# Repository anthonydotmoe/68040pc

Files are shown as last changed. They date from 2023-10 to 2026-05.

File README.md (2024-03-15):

# 68040pc

Welcome to the `68040pc` (working name) project, an ambitious endeavor to build
a general-purpose computer platform powered by the Motorola 68040 (or, in this
case, the 68LC040) CPU. Inspired by creations like Ben Eater's breadboard 6502
computer and me finding a 68LC040 in a bin, this project seeks to bring the
charm of vintage computing into the modern era with a twist of power and
utility. Call me crazy, but I expect to be able to use this machine when it's
done.

## Status

The `testboard` design is almost complete. I'm going to sleep on the design
before ordering boards. The FPGA does address decoding and interrupt
management and will contain a sound core to output some cool beeps through
the I2S DAC module. I'm pleased with how the project is going so far!

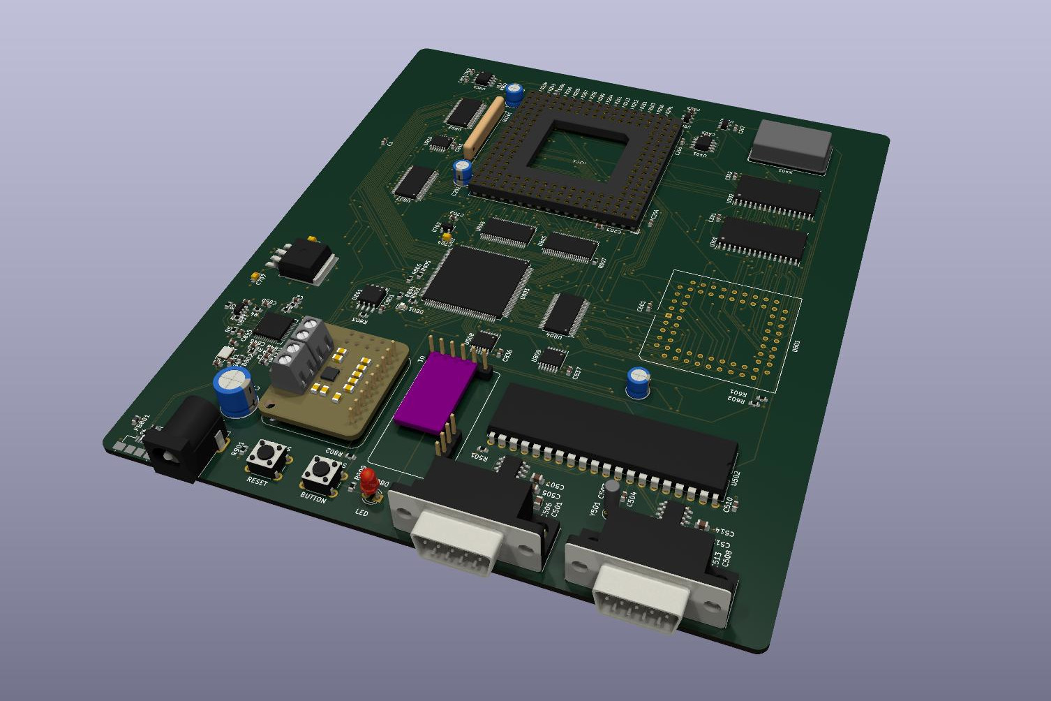
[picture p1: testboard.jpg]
testboard Render


## Objectives

The `68040pc` aims to be versatile and user-friendly, with the following
capabilities:
- **Input/Output**: Support for keyboard (text input) and mouse for GUI
  interactions.
- **Display**: Text display for command-line operations and a graphics display
  ready for GUI applications.
- **Storage**: Compatibility with standard bulk storage devices, including
  floppies and hard drives.
- **OS**: Capability to run a preemptive multitasking operating system.
- **Expansion**: A robust expansion system, ensuring the platform remains
  relevant and adaptable after its initial production.

## Performance Expectations

With the integration of the 68040 CPU and the potential to accommodate up to
512MB of RAM, I anticipate the `68040pc` will rival the performance metrics of
systems like the Amiga, especially in terms of computational power. Although the
base system might not match the Amiga's graphical prowess, there's potential for
future enhancements via expansion cards to bring it to that level.

## Learning and Documentation

This journey isn't just about creating a new machine—it's a significant learning
curve for me, and I want it to serve as an educational resource for others.
Every step of the way, the system will be meticulously documented. From design
decisions to implementation nuances, the goal is to demystify the process and
make the knowledge accessible to all.

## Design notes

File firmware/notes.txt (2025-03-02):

- Expose interrupt generator peripheral from FPGA

POST Routine:

- Do test of SRAM
	- SRAM works -> relocate VBR to SRAM
- Test interrupts
	- Interrupts work, serial port can use them
- Test serial port?

FPGA BASE:0x80000000
	* 0x00.l - Status
	* 0x04.b - Fire interrupt (number written, one cycle)

MMU Transparent translation

Addr		Device		DataC		InstC
0000_0000	ROM		01		01
2000_0000	DUART		11		11
3000_0000	SRAM		01		01
8000_0000	FPGA		11		11

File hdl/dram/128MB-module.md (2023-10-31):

SAMS-side pin 1 to pin 72 are 0-7
OKI-side  pin 72 to pin 1 are 8-15

| DRAM Chip # | CAS Line | RAS Line | Data Lines |
|---|---|---|---|
| 0 | CAS0 | RAS0 | D0-D3 |
| 2 | CAS0 | RAS0 | D4-D7 |
| 4 | CAS1 | RAS0 | D8-D11 |
| 6 | CAS1 | RAS0 | D12-D15 |
| 1 | CAS2 | RAS2 | D16-D19 |
| 3 | CAS2 | RAS2 | D20-D23 |
| 5 | CAS3 | RAS2 | D24-D27 |
| 7 | CAS3 | RAS2 | D28-D31 |
|---------------------------------------------------|
| 8 | CAS0 | RAS1 | D0-D3 |
| 10 | CAS0 | RAS1 | D4-D7 |
| 12 | CAS1 | RAS1 | D8-D11 |
| 14 | CAS1 | RAS1 | D12-D15 |
| 9 | CAS2 | RAS3 | D16-D19 |
| 11 | CAS2 | RAS3 | D20-D23 |
| 13 | CAS3 | RAS3 | D24-D27 |
| 15 | CAS3 | RAS3 | D28-D31 |

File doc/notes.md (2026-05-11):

# Ideas

* Use ATF1508 for the DRAM controller. This leaves more pins for a non-BGA FPGA
  to be useful.

## EDO DRAM Bursting Support

Use four matching 72-pin EDO SIMMs as one 512 MiB interleaved memory array, not
as four separate linear banks.

Each SIMM remains a 32-bit data source/sink. The CPU data bus is still only 32
bits wide. Only one SIMM drives the 68040 data bus per transfer beat.

Address mapping:

| Address Bits | Mapping |
|---|---|
| A1..A0 |  byte lane within longword |
| A3..A2 |  SIMM select / longword-in-16-byte cache line |
| A15..A4 |  12-bit DRAM column |
| A27..A16 |  12-bit DRAM row |
| A28 |  SIMM rank select |

A 16-byte cache line is distributed as:

| | |
|-----|---|
| +0  | SIMM 0 |
| +4  | SIMM 1 |
| +8  | SIMM 2 |
| +12 | SIMM 3 |

For burst/line fills, initialize the SIMM selector from A3..A2, then increment
modulo 4 each accepted /TA beat. This supports critical-word-first ordering:

| A[3:2] | Order |
|---|---|
| 00 | 0,1,2,3 |
| 01 | 1,2,3,0 |
| 10 | 2,3,0,1 |
| 11 | 3,0,1,2 |

All SIMMs share the same row/column address for a given line. With 12 column
bits and four 32-bit SIMMs interleaved, one open DRAM row group covers:

4096 columns × 16 bytes = 64 KiB

So naturally aligned 4 KiB MMU pages never straddle DRAM row groups.

# Problems

## XR68C681 DUART

I attempted to write a simple monitor ROM program for the 68040pc pretty early
on. I ran into problems when I reached the point of wanting user input.

### Original symptom

After not being able to debug my monitor CLI logic, I made a test program
intended to behave like a simple polling echo loop:

1. Poll SRA until `RxRDY` is set.
2. Read one byte from RBA
3. Poll SRA until `TxRDY` is set.
4. Write that byte to TBA.
5. Repeat.

The observed failure was that sending one character to the computer would
eventually result in an extra character being handled. At first this looked
like:

1. Host sends one character.
2. 68040 reads one character.
3. 68040 writes it to TBA.
4. Then the DUART appears to have another received character pending.

My early suspicion was that the DUART transmit write might somehow be making
`RxRDY` true, either through accidental loopback, or through my novice-level
Verilog controlling the bus behavior.

### Troubleshooting

* Terminal behavior

  I considered that maybe my tried and true `picocom` terminal emulator was the
  problem. I had ChatGPT generate a test program in Python that wrote out single
  bytes to the serial port, but no change was observed.

* Rewired DUART address lines:

  I moved the DUART `RS[4:1]` lines from `{ A[3:2], PA[1:0] }` to `A[5:2]`. The
  goal was to force accesses to always land on the same byte lane and remove
  byte-lane steering from the MC68150 as a varible. No change.

* Checked whether the 68150 was generating multiple accesses

  If the CPU was issuing a word or long word access to the DUART address space,
  the 68150 would generate multiple accesses to fill in the request. Probing the
  bus while testing did not give any evidence of duplicate DUART select cycles.

* Checked address setup relative to `/CS`

  With a logic analyzer, I determined that address setup time going into `/CS`
  was well within spec.

* Verified that the DUART was in the correct mode

  I changed the initialization routine to purposefully set up remote loopback
  mode, as the bits that do that were previously not being set. Remote loopback
  mode behaves completely differently, and behaves as expected. Characters are
  sent right through from the RX shift register to the TX shift register.

  I also tried automatic echo mode, and it behaved as expected.

* Considered accidental multidrop mode

  I remember seeing something about a different mode in the datasheet, so maybe
  I had the DUART in that mode. After looking into it further, the symptoms
  aren't consistent with having the DUART in the multidrop mode.

* Crystal wiring

  I had wired in the crystal to the DUART without much thought, and it turns out
  it is not what the datasheet has specified. I have capacitors inline with the
  crystal, but the reference design uses capacitors to ground on X1/CLK and X2.
  The DUART behaved well enough that I didn't think it would be possible for it
  to be an issue, but I was running out of things to try.

  I used a PLL in the FPGA to synthesize a 3.6805 MHz 3.3V clock signal. This is
  about 0.16% low relative to 3.6864 MHz, but it was within the error margin.
  No change.

* RxA/external serial line checks

  I scoped RxA and did not see any evidence of more than one character on the
  line for a given keypress in the terminal.

### Yet to confirm

* I haven't thoroughly checked the reset line on the DUART. I assume it's
  working because the first character the test program receives works without
  issue, but any subsequent characters end up repeating nonsense. However, I
  haven't completely tested it.

* The bus interface is not entirely without suspicion. I feel like I know enough
  about the 68040 bus to have wired everything and got the HDL correct, but I'm
  far from an expert on this and still have doubts.

### Remaining failure modes to consider

1. Reset/init does not fully clear the DUART receiver/FIFO/status state.
2. RBA read-clear behavior is not reliably recognized.
3. TBA write or nearby DUART bus access subtly corrupts internal state.
4. Register-select/read/write timing is marginal despite the cycle looking
   generally normal.
5. Data bus behavior causes stale/wrong RBA values to be read.
6. XR68C681 clone-specific quirk, board-level sensitivity, or undocumented
   behavior.

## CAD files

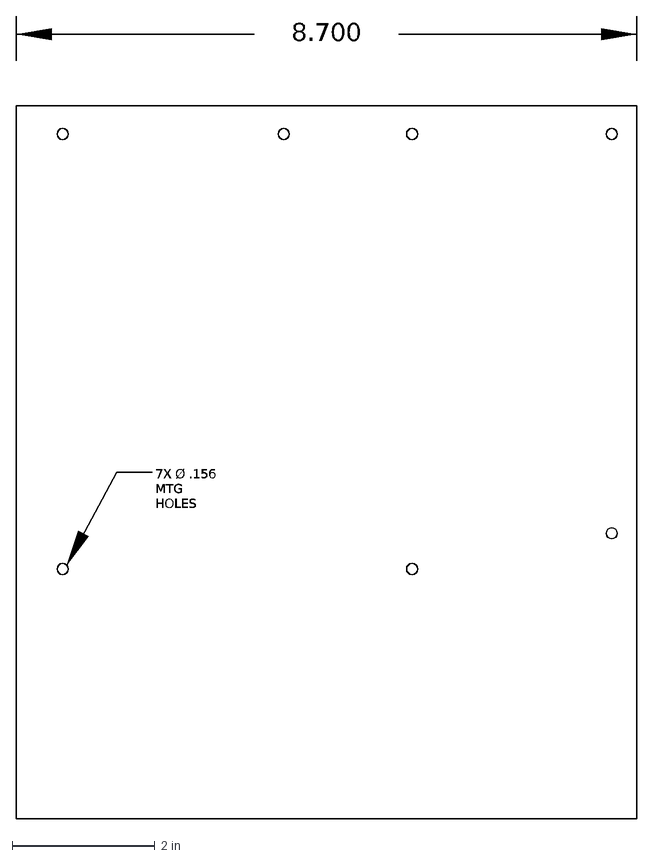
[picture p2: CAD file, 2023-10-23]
doc/board.dxf
7X Ø .156 MTG HOLES
8.700

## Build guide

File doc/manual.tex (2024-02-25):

\documentclass{article}

%\usepackage[letterpaper, margin=1in]{geometry}
\usepackage[letterpaper]{geometry}
\usepackage{bold-extra}
\usepackage{bytefield}
\usepackage{tabularx}
\usepackage{threeparttable}
\usepackage{xifthen}
\usepackage{xparse}
\usepackage{xspace}

\newcommand{\systemname}[0]{68040pc\xspace}

\makeatletter
\newcommand*{\textoverline}[1]{$\overline{\hbox{#1}}\m@th$}
\makeatother

\newcommand{\textss}[1]{$_{\hbox{#1}}$}

\NewDocumentCommand{\addr}{mm}{%
  \IfNoValueTF{#2}
  	{\texttt{\$#1}}
	{\mbox{\texttt{\$#1}-\texttt{\$#2}}}
}

\newcommand{\memsection}[4]{
	\bytefieldsetup{bitheight=#3\baselineskip}
	\bitbox[]{10}{
		\texttt{#1}
		\\ \vspace{#3\baselineskip} \vspace{-2\baselineskip} \vspace{- #3pt}
		\texttt{#2}
	}
	\bitbox{16}{#4}
}

\begin{document}

\begin{titlepage}
	\begin{center}
		\vspace*{1cm}

		\Huge
		\textbf{\systemname Specification}

		\vspace{0.5cm}
		\LARGE
		A Personal Computer Platform

		\vspace{1.5cm}
		\textbf{Anthony Guerrero}

		\vfill

		\normalsize
		Document Revision 0.0.1

		\vspace{0.8cm}
	\end{center}
\end{titlepage}

\section{System Overview}

\subsection{Design Goal}
The primary objective of the \systemname is to construct a personal computer
platform that aligns with the capabilities and aesthetics of computing systems
from the 1990s. The system is not merely a reflection of retro hardware but a
modern interpretation emphasizing complete transparancy, user understanding,
and modifiability. The design principles prioritize open-source documentation,
source code, and hardware description language (HDL) to empower users and
enthusiasts to understand, modify, and expand upon the system.

\subsection{Key Features}
\begin{itemize}
	\item \textbf{Open Architecture:} An open-source ethos is at the core of the
	project. All documentation, designs, and code associated with this
	system will be freely accessible and modifiable by the end-users and
	community.

	\item \textbf{MC68040 Processor:} Serving as the heart of the system, this 32-bit
	microprocessor offers a blend of performance and functionality suitable
	for a wide range of computing tasks. It's Instruction Set Architecture
	(ISA) and built-in MMU lends itself well to implementing UNIX-like
	operating systems.

	\item \textbf{Flexible Expansion:} The platform is designed with expansion and
	modularity in mind, featuring an ``Expansion Bus'' architecture to
	facilitate the addition of new components. The bus dynamically assigns
	memory space to bus members, bypassing address conflicts and setup
	jumpers.

	\item \textbf{Integrated FPGA:} Utilizing the iCE40-HX4K FPGA, with full access
	to the CPU bus, most glue logic and peripheral controllers can be
	implemented and modified after the design is finalized.

	\item \textbf{Dynamic RAM Controller:} With four 72-pin SIMM slots, the platform
	supports up to 512MB of main system memory. (3.3v only!)

	\item \textbf{Standard Form Factor:} The PCB will be sized to fit in a pre-ATX
	form factor called ``Baby AT''. This allows for eight expansion slots,
	a DIN-5 sized cutout for a keyboard, and simple power management.
\end{itemize}

\subsection{System Philosophy}

Beyond the technical specifications, this project embodies a philosophy of
transparency, education, and user empowerment. The system is not just a
computing platform but a testament to the ethos that technology should be
understandable, modifiable, and, above all, open. Whether for education,
nostalgia, or innovation, this platform seeks to be a canvas for users to
explore the intricacies of computing, reminiscent of an era when personal
computing was just blossoming.

\section{Hardware}

\subsection{CPU}

The Motorola MC68LC040 was chosen because I found it in a box. The
\textoverline{MDIS} and \textoverline{IPLx} lines are tied high by pull-up
resistors during normal operation, which has the effect of enabling the small
output buffers and non-multiplexed bus mode on the 68040 CPU. Designing the
motherboard with this in mind makes the system also compatible with the standard
68040.

\subsection{SRAM}

There are 512KB of SRAM for the boot ROM to use. During boot, information about
the hardware installed in the system is collected into a device attribute table
and is communicated to the operating system.

\subsection{DRAM}

Four 72-pin SIMM slots provide the bulk RAM for the system. Each SIMM's
\textoverline{RAS} lines are tied together and sent to the memory controller,
\textoverline{CAS} lines are routed separately. The system should support
commodity 5V 72-pin SIMMs which were available for the 486 and early Pentium
platforms.

The SIMMs I have (Keystron MK16DS3232LP-50) have (16) 16M $\times$ 4-bit DRAMs
per module. The module is layed out as listed in Figure \ref{map:keystron}, the
DRAM chip numbers are listed from 0-7 for the front side and 8-15 for the back
side. I've ordered the table so Bank 0 is listed first in order of Data Line.
Next, Bank 1 is listed in the same order.

\begin{figure}[]
	\caption{Keystron MK16DS3232LP-50 module layout}
	\label{map:keystron}
\begin{center}
	\begin{tabularx}{0.75\textwidth}{X X X X}
		DRAM Chip \# & CAS Line & RAS Line & Data Lines\\
		\hline \\
		0  & \textoverline{CAS0} & \textoverline{RAS0} & D0-D3\\
		2  & \textoverline{CAS0} & \textoverline{RAS0} & D4-D7\\
		4  & \textoverline{CAS1} & \textoverline{RAS0} & D8-D11\\
		6  & \textoverline{CAS1} & \textoverline{RAS0} & D12-D15\\
		1  & \textoverline{CAS2} & \textoverline{RAS2} & D16-D19\\
		3  & \textoverline{CAS2} & \textoverline{RAS2} & D20-D23\\
		5  & \textoverline{CAS3} & \textoverline{RAS2} & D24-D27\\
		7  & \textoverline{CAS3} & \textoverline{RAS2} & D27-D31\\
		8  & \textoverline{CAS0} & \textoverline{RAS1} & D0-D3\\
		10 & \textoverline{CAS0} & \textoverline{RAS1} & D4-D7\\
		12 & \textoverline{CAS1} & \textoverline{RAS1} & D8-D11\\
		14 & \textoverline{CAS1} & \textoverline{RAS1} & D12-D15\\
		9  & \textoverline{CAS2} & \textoverline{RAS3} & D16-D19\\
		11 & \textoverline{CAS2} & \textoverline{RAS3} & D20-D23\\
		13 & \textoverline{CAS3} & \textoverline{RAS3} & D24-D27\\
		15 & \textoverline{CAS3} & \textoverline{RAS3} & D27-D31\\
	\end{tabularx}
\end{center}
\end{figure}

\subsection{Boot ROM}

The boot ROM program is stored on the same SPI EEPROM thats used to configure
the FPGA. Accesses to ROM space are routed through the FPGA, which performs the
required access to the SPI ROM and returns the data back to the CPU. This was
done to facilitate rapid prototyping by providing a fast and available interface
to update the ROM.

\subsection{I2C Bus}

I2C is used on-board for communication with the Real-Time Clock (DS1307) and
other devices. (Temperature sensors/Fan controllers, etc.)

\section{Memory Map}

The memory map of the system is mostly organized into 128MB sections, using the
\texttt{A[31:27]} signals to select them (Figure \ref{map:sysmem}). This means
the FPGA only needs 5 address lines to decode and provide chip select signals
for the on-board devices. It also takes \texttt{A[1:0]} from the MC68150 and
\texttt{A[18:2]} from the 68040 for addressing registers internal to the FPGA,
discriminating between devices in the System Registers space, and for bridging
up to 512KB of SPI flash to the system.

\begin{figure}[]
	\caption{System Memory Map}
	\label{map:sysmem}
	\vspace{2ex}
	\begin{bytefield}{12}
		\memsection{0000 0000}{}{2}{ROM Area}\\
		\memsection{0800 0000}{}{2}{On-board SRAM}\\
		\memsection{1000 0000}{}{2}{On-board DRAM}\\
		\memsection{1800 0000}{}{4}{-}\\
		\memsection{3800 0000}{}{2}{System Registers}\\
		\memsection{4000 0000}{}{8}{Expansion Area}\\
		\memsection{8000 0000}{}{4}{-}\\
		\memsection{B800 0000}{}{2}{EXP Configuration}\\
		\memsection{C000 0000}{FFFF FFFF}{4}{Expansion Area}\\
		% \memsection{ff00 0000}{ffff ffff}{3}{Expansion Card Area}\\
	\end{bytefield}
\end{figure}

\section{Expansion Bus}

The system provides a Zorro III-inspired expansion slot bus, the main feature of
which is dynamic memory mapping of add-in devices. 

\subsection{Design Goals}

\begin{itemize}
	\item \textbf{Expansion and Flexibility:} A primary aim of the expansion
	bus is to ensure that the design does not inherently limit future
	enhancements or adaptations.

	\item \textbf{Performance:} The bus shouldn't unnecessarily constrain
	the bandwidth of any peripheral that connects to it, including the
	bus-master. In practice, this means that it should pretty much be a
	minor extension to the local bus.

	\item \textbf{Support for Varied Devices:} The bus should accomodate any
	device which can interface with the MC68040's local bus. Unfortunately,
	this means 16 or 8-bit devices will need logic on the card to support
	``resizing'' the accesses.

	\item \textbf{Reliability:} Ensure robust operation and avoid
	complications that might make the system prone to errors.
\end{itemize}

\subsection{Bus Architecture}

The design of the expansion bus draws heavily from the Zorro III expansion bus
designed for the Amiga 3000 and 4000 series of computers, but differs in many
key ways which make it incompatible.

\subsubsection{Card Configuration}

Cards must ground the \textoverline{CDET} line to be included in the
bus, and therefore is a requirement for complying with this bus specification.
If the card doesn't pull this line down, or there isn't a card plugged into an
expansion slot, the \textoverline{CFGIN} line will be bridged to the
\textoverline{CFGOUT} line for that expansion slot.

\subsubsection{Bus Cycles}

\subsubsection{Arbitration/Mastering}

\subsubsection{Cache Support}

While the expansion bus doesn't have any cache consistency mechanisms for
managing caches between several caching bus masters, it does allow cards that
absolutely must not be cached to assert a cache inhibit line,
\textoverline{CI}, on a per-cycle basis. This cache management is mainly useful
for support of I/O and other devices that shouldn't be cached.

\subsubsection{Interrupts}

A card supporting interrupts has on-board registers to store one or more vector
numbers. The numbers are obtained from the OS by the device driver for the card
and the card/driver combination must be able to handle the situation in which no
additional vectors are available.

\subsection{Signal Description}

\subsubsection{Power Connections}

\begin{itemize}
	\item{\textbf{Digital Ground (GND)}} This is the digital supply ground
	used by all expansion cards as the return path for all expansion
	supplies.

	\item{\textbf{Main Supply (+5VDC)}} This is the main power supply for
	all expanion cards. (Define power specification)

\end{itemize}

\subsubsection{Clock Signals}

\begin{itemize}
	\item{\textbf{TBD...}}
\end{itemize}

\subsubsection{System Control Signals}

\begin{itemize}
	\item{\textbf{Hardware Bus Error}}

	\item{\textbf{System Interrupts}}
\end{itemize}

\subsubsection{Slot Control Signals}

\begin{itemize}

	\item{\textbf{Configuration Chain
	(\textoverline{\scshape CFGINn},
	\textoverline{\scshape CFGOUTn})}} The slot configuration mechanism uses
	the bus signals \textoverline{\scshape CFGOUTn} and
	\textoverline{\scshape CFGINn}, where ``\textsc{n}'' refers to the slot
	number. Each slot has its own version of both signals, which make up the
	\textit{configuration chain} between slots. Each subsequent
	\textoverline{CFGIN} is a result of all previous
	\textoverline{CFGOUT}s, going from slot 0 to the last slot on the
	expansion bus.

	During the autoconfiguration process, an unconfigured card responds to
	the address space X if its \textoverline{\scshape CFGINn} is asserted.
	All unconfigured cards start up with \textoverline{\scshape CFGOUTn}
	negated. When configured, a card will assert its
	\textoverline{\scshape CFGOUTn} which results in the
	\textoverline{\scshape CFGINn} of the next slot being asserted.
	Backplane logic automatically passes on the state of the previous
	\textoverline{\scshape CFGOUTn} to the next
	\textoverline{\scshape CFGINn} for any slot not occupied by a card.

	\item{\textbf{Card Detect (\textoverline{CDET})}} This signal is to
	always be attached to ground by cards to allow them to participate in
	the expansion bus. This signal is part of the backplane circuitry that
	allows the configuration chain to function.

\end{itemize}

\subsubsection{DMA Control Signals}

\begin{itemize}
	\item{\textbf{TBD...}}
\end{itemize}

\subsubsection{Address and Related Control Signals}

\begin{itemize}

	\item{\textbf{Address Bus (A\textss{0}-A\textss{31})}} This is the
	expansion address bus, which is driven by the bus master.

\end{itemize}

\subsubsection{Data and Related Control Signals}

\begin{itemize}
	\item{\textbf{Data Bus (D\textss{0}-D\textss{31})}} This is the
	expansion data bus, which is driven by either the master or the slave
	when ``'' is asserted by the master. It's valid for reads when
	\textoverline{DTACK} is asserted by the slave.

	\item{\textbf{Transfer Acknowledge (\textoverline{TA})}} This
	signal is used to normally terminate an expansion bus cycle. The slave
	is always responsible for driving this signal. For a read cycle, it
	asserts \textoverline{TA} as soon as it has driven valid data onto
	the bus. For a write cycle, it asserts \textoverline{TA} as soon as
	it's done with the data.

\item{\textbf{Transfer Burst Inhibit/Transfer Cache Inhibit (\textoverline{TBI}/\textoverline{TCI})}}
	This line is asserted at the same time as \textoverline{TA} to indicate
	to the bus master that the cycle must not be cached, or that that the
	cycle can't be completed as a burst transfer.
\end{itemize}

\subsection{Electrical Specifications}

\subsubsection{Standard Signals}

The majority of signals on the bus are in this group. These are the bussed
signals, driven actively on the bus by F-series (or compatible) drivers, usually
tri-stated when ownership of the signal changed for master and slave, and
generally terminated with a 220$\Omega$/330$\Omega$ thevenin terminator.

\begin{center}
	\begin{tabularx}{0.75\textwidth}{X X X}
		A\textss{0}-A\textss{31} & D\textss{0}-D\textss{31} & R/\textoverline{W} \\
		FC\textss{0}-FC\textss{2} & & 
	\end{tabularx}
\end{center}

\subsubsection{Clock Signals}

\subsubsection{Open Collector Signals}

Many of the bus signals are shared via open collector or open drain outputs
rather than via tri-stated signals. A backplane resistor pulls these lines high,
cards only drive the line low.

\begin{center}
	\begin{tabularx}{0.75\textwidth}{X X X}
		\textoverline{TA} & \textoverline{TCI}/\textoverline{TBI} & \textoverline{TEA} \\
		\textoverline{RESET} & R/\textoverline{W} & 
	\end{tabularx}
\end{center}

\subsubsection{Non-bussed signals}

\begin{center}
	\begin{tabularx}{0.75\textwidth}{X X X}
		\textoverline{\scshape CFGINn} & \textoverline{\scshape IRQn} & R/\textoverline{W} \\
		\textoverline{\scshape CFGOUTn} & & 
	\end{tabularx}
\end{center}

\subsubsection{Slot Power Availability}

The system power for the expansion bus is based on the slot configurations. A
backplane is always free to supply extra power, but it must meet the minimum
requirements specified here. All cards must be designed with the minimum
specifications in mind, especially the tolerances.

\begin{center}
	\begin{tabularx}{0.75\textwidth}{X X}
		Pin & Supply \\
		\hline \\
		X, X	& $+$5 VDC $\pm$5\% @ 2A \\
		X	& $+$12 VDC $\pm$5\% @ 500mA \\
	\end{tabularx}
\end{center}

\subsection{Mechanical Specifications}

\subsection{Expansion Slot Pin Assignments}

%\begin{figure}[h]
	\begin{centering}

	\begin{threeparttable}
	\caption{Expansion Bus Connector Pinout}
	\begin{tabularx}{\textwidth}
		{| c | X || c | X || c | X |}
		\hline
		Pin & Name & Pin & Name & Pin & Name \\
		\hline\hline
		a1  & NC\tnote{1}	& b1  &	D\textss{16}	& c1  &	NC 		\\
		\hline
		a2  & NC		& b2  &	D\textss{17}	& c2  &	NC 		\\
		\hline
		a3  & D\textss{0}	& b3  &	D\textss{18}	& c3  &	NC 		\\
		\hline
		a4  & D\textss{2}	& b4  &	D\textss{19}	& c4  &	NC 		\\
		\hline
		a5  & D\textss{4}	& b5  &	D\textss{20}	& c5  &	NC 		\\
		\hline
		a6  & D\textss{6}	& b6  &	D\textss{21}	& c6  &	NC 		\\
		\hline
		a7  & D\textss{8}	& b7  &	D\textss{22}	& c7  &	NC 		\\
		\hline
		a8  & D\textss{10}	& b8  &	D\textss{23}	& c8  &	NC 		\\
		\hline
		a9  & D\textss{12}	& b9  &	D\textss{24}	& c9  &	NC 		\\
		\hline
		a10 & D\textss{14}	& b10 &	D\textss{25}	& c10 &	NC 		\\
		\hline
		a11 & GND		& b11 &	D\textss{26}	& c11 &	NC 		\\
		\hline
		a12 & A\textss{1}	& b12 &	D\textss{27}	& c12 &	NC 		\\
		\hline
		a13 & A\textss{3}	& b13 &	D\textss{28}	& c13 &	NC 		\\
		\hline
		a14 & A\textss{5}	& b14 &	D\textss{29}	& c14 &	NC 		\\
		\hline
		a15 & A\textss{7}	& b15 &	D\textss{30}	& c15 &	NC 		\\
		\hline
		a16 & A\textss{9}	& b16 &	D\textss{31}	& c16 &	NC 		\\
		\hline
		a17 & A\textss{11}	& b17 &	A\textss{0}	& c17 &	NC 		\\
		\hline
		a18 & A\textss{13}	& b18 &	A\textss{0}	& c18 &	NC 		\\
		\hline
		a19 & A\textss{15}	& b19 &	NC		& c19 &	NC 		\\
		\hline
		a20 & A\textss{17}	& b20 &	NC		& c20 &	NC 		\\
		\hline
		a21 & A\textss{19}	& b21 &	NC		& c21 &	NC 		\\
		\hline
		a22 & NC		& b22 &	NC		& c22 &	NC 		\\
		\hline
		a23 & NC		& b23 &	NC		& c23 &	NC 		\\
		\hline
		a24 & NC		& b24 &	NC		& c24 &	NC 		\\
		\hline
		a25 & NC		& b25 &	NC		& c25 &	NC 		\\
		\hline
		a26 & NC		& b26 &	NC		& c26 &	NC 		\\
		\hline
		a27 & NC		& b27 &	NC		& c27 &	NC 		\\
		\hline
		a28 & NC		& b28 &	NC		& c28 &	NC 		\\
		\hline
		a29 & NC		& b29 &	NC		& c29 &	NC 		\\
		\hline
		a30 & NC		& b30 &	NC		& c30 &	NC 		\\
		\hline
		a31 & NC		& b31 &	NC		& c31 &	NC 		\\
		\hline
		a32 & NC		& b32 &	NC		& c32 &	NC 		\\
		\hline
	\end{tabularx}
	\begin{tablenotes}
	\item [1] This means it's not connected. You knew that though. This
	footnote is only here so I remember how to do it later.
	\end{tablenotes}
	\end{threeparttable}
	\end{centering}
% \end{figure}

\section{Interrupt System}

\section{Special Thanks}
\setlength\parindent{0pt}

\textbf{Ben Eater} for creating engaging videos on computer engineering,
inspiring me to build a computer of my own.

\textbf{Lawrence Manning} MAXI030

\textbf{Stephen Moody} Y Ddraig(030)

\textbf{Dave Haynie} Author of ``The Zorro III Bus Specification''

\end{document}

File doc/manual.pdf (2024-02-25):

# 68040pc Specification

# A Personal Computer Platform

# Anthony Guerrero

Document Revision 0.0.1

## 1 System Overview

### 1.1 Design Goal

The primary objective of the 68040pc is to construct a personal computer platform that aligns with the capabilities and aesthetics of computing systems from the 1990s. The system is not merely a reflection of retro hardware but a modern interpretation emphasizing complete transparancy, user understanding, and modifiability. The design principles prioritize open-source documentation, source code, and hardware description language (HDL) to empower users and enthusiasts to understand, modify, and expand upon the system.

### 1.2 Key Features

- Open Architecture: An open-source ethos is at the core of the project. All documentation, designs, and code associated with this system will be freely accessible and modifiable by the end-users and community.
- MC68040 Processor: Serving as the heart of the system, this 32-bit microprocessor offers a blend of performance and functionality suitable for a wide range of computing tasks. It’s Instruction Set Architecture (ISA) and built-in MMU lends itself well to implementing UNIX-like operating systems.
- Flexible Expansion: The platform is designed with expansion and modularity in mind, featuring an “Expansion Bus” architecture to facilitate the addition of new components. The bus dynamically assigns memory space to bus members, bypassing address conflicts and setup jumpers.
- Integrated FPGA: Utilizing the iCE40-HX4K FPGA, with full access to the CPU bus, most glue logic and peripheral controllers can be implemented and modified after the design is finalized.
- Dynamic RAM Controller: With four 72-pin SIMM slots, the platform supports up to 512MB of main system memory. (3.3v only!)
- Standard Form Factor: The PCB will be sized to fit in a pre-ATX form factor called “Baby AT”. This allows for eight expansion slots, a DIN-5 sized cutout for a keyboard, and simple power management.

### 1.3 System Philosophy

Beyond the technical specifications, this project embodies a philosophy of transparency, education, and user empowerment. The system is not just a computing platform but a testament to the ethos that technology should be understandable, modifiable, and, above all, open. Whether for education, nostalgia, or innovation, this platform seeks to be a canvas for users to explore the intricacies of computing, reminiscent of an era when personal computing was just blossoming.

1

## 2 Hardware

### 2.1 CPU

The Motorola MC68LC040 was chosen because I found it in a box. The MDIS and IPLx lines are tied high by pull-up resistors during normal operation, which has the effect of enabling the small output buffers and non-multiplexed bus mode on the 68040 CPU. Designing the motherboard with this in mind makes the system also compatible with the standard 68040.

### 2.2 SRAM

There are 512KB of SRAM for the boot ROM to use. During boot, information about the hardware installed in the system is collected into a device attribute table and is communicated to the operating system.

### 2.3 DRAM

Four 72-pin SIMM slots provide the bulk RAM for the system. Each SIMM’s RAS lines are tied together and sent to the memory controller, CAS lines are routed separately. The system should support commodity 5V 72-pin SIMMs which were available for the 486 and early Pentium platforms. The SIMMs I have (Keystron MK16DS3232LP-50) have (16) 16M × 4-bit DRAMs per module. The module is layed out as listed in Figure 1, the DRAM chip numbers are listed from 0-7 for the front side and 8-15 for the back side. I’ve ordered the table so Bank 0 is listed first in order of Data Line. Next, Bank 1 is listed in the same order.

### 2.4 Boot ROM

The boot ROM program is stored on the same SPI EEPROM thats used to configure the FPGA. Accesses to ROM space are routed through the FPGA, which performs the required access to the SPI ROM and returns the data back to the CPU. This was done to facilitate rapid prototyping by providing a fast and available interface to update the ROM.

### 2.5 I2C Bus

I2C is used on-board for communication with the Real-Time Clock (DS1307) and other devices. (Temperature sensors/Fan controllers, etc.)

## 3 Memory Map

The memory map of the system is mostly organized into 128MB sections, using the A[31:27] signals to select them (Figure 2). This means the FPGA only needs 5 address lines to decode and provide chip select signals for the on-board devices. It also takes A[0:1] from the MC68150 and A[2:5] from the 68040 for addressing registers internal to the FPGA and discriminating between devices in the System Registers space.

2

Figure 1: Keystron MK16DS3232LP-50 module layout

DRAM Chip # | CAS Line | RAS Line | Data Lines
0 | CAS0 | RAS0 | D0-D3
2 | CAS0 | RAS0 | D4-D7
4 | CAS1 | RAS0 | D8-D11
6 | CAS1 | RAS0 | D12-D15
1 | CAS2 | RAS2 | D16-D19
3 | CAS2 | RAS2 | D20-D23
5 | CAS3 | RAS2 | D24-D27
7 | CAS3 | RAS2 | D27-D31
8 | CAS0 | RAS1 | D0-D3
10 | CAS0 | RAS1 | D4-D7
12 | CAS1 | RAS1 | D8-D11
14 | CAS1 | RAS1 | D12-D15
9 | CAS2 | RAS3 | D16-D19
11 | CAS2 | RAS3 | D20-D23
13 | CAS3 | RAS3 | D24-D27
15 | CAS3 | RAS3 | D27-D31

## 4 Expansion Bus

The system provides a Zorro III-inspired expansion slot bus, the main feature of which is dynamic memory mapping of add-in devices.

### 4.1 Design Goals

- Expansion and Flexibility: A primary aim of the expansion bus is to ensure that the design does not inherently limit future enhancements or adaptations.
- Performance: The bus shouldn’t unnecessarily constrain the bandwidth of any peripheral that connects to it, including the bus-master. In practice, this means that it should pretty much be a minor extension to the local bus.
- Support for Varied Devices: The bus should accomodate any device which can interface with the MC68040’s local bus. Unfortunately, this means 16 or 8-bit devices will need logic on the card to support “resizing” the accesses.
- Reliability: Ensure robust operation and avoid complications that might make the system prone to errors.

### 4.2 Bus Architecture

The design of the expansion bus draws heavily from the Zorro III expansion bus designed for the Amiga 3000 and 4000 series of computers, but differs in many key ways which make it incompatible.

3

Figure 2: System Memory Map

0000 0000 | ROM Area
0800 0000 | On-board SRAM
1000 0000 | On-board DRAM

1800 0000
3800 0000 | System Registers

4000 0000

Expansion Area

8000 0000
B800 0000 | EXP Configuration

C000 0000

FFFF FFFF

Expansion Area

4

### 4.2.1 Card Configuration

Cards must ground the CDET line to be included in the bus, and therefore is a requirement for complying with this bus specification. If the card doesn’t pull this line down, or there isn’t a card plugged into an expansion slot, the CFGIN line will be bridged to the CFGOUT line for that expansion slot.

### 4.2.2 Bus Cycles

### 4.2.3 Arbitration/Mastering

### 4.2.4 Cache Support

While the expansion bus doesn’t have any cache consistency mechanisms for managing caches between several caching bus masters, it does allow cards that absolutely must not be cached to assert a cache inhibit line, CI, on a per-cycle basis. This cache management is mainly useful for support of I/O and other devices that shouldn’t be cached.

### 4.2.5 Interrupts

A card supporting interrupts has on-board registers to store one or more vector numbers. The numbers are obtained from the OS by the device driver for the card and the card/driver combination must be able to handle the situation in which no additional vectors are available.

### 4.3 Signal Description

### 4.3.1 Power Connections

- Digital Ground (GND) This is the digital supply ground used by all expansion cards as the return path for all expansion supplies.
- Main Supply (+5VDC) This is the main power supply for all expanion cards. (Define power specification)

### 4.3.2 Clock Signals

- TBD...

### 4.3.3 System Control Signals

- Hardware Bus Error
- System Interrupts

### 4.3.4 Slot Control Signals

- Configuration Chain (CFGINn, CFGOUTn) The slot configuration mechanism uses the bus signals CFGOUTn and CFGINn, where “n” refers to the slot number. Each slot has its own version of both signals, which make up the configuration chain between slots. Each

5

subsequent CFGIN is a result of all previous CFGOUTs, going from slot 0 to the last slot on the expansion bus.

During the autoconfiguration process, an unconfigured card responds to the address space X if its CFGINn is asserted. All unconfigured cards start up with CFGOUTn negated. When configured, a card will assert its CFGOUTn which results in the CFGINn of the next slot being asserted. Backplane logic automatically passes on the state of the previous CFGOUTn to the next CFGINn for any slot not occupied by a card.

- Card Detect (CDET) This signal is to always be attached to ground by cards to allow them to participate in the expansion bus. This signal is part of the backplane circuitry that allows the configuration chain to function.

### 4.3.5 DMA Control Signals

- TBD...

### 4.3.6 Address and Related Control Signals

- Address Bus (A0
-A31) This is the expansion address bus, which is driven by the bus master.

### 4.3.7 Data and Related Control Signals

- Data Bus (D0
-D31) This is the expansion data bus, which is driven by either the master or the slave when “” is asserted by the master. It’s valid for reads when DTACK is asserted by the slave.
- Transfer Acknowledge (TA) This signal is used to normally terminate an expansion bus cycle. The slave is always responsible for driving this signal. For a read cycle, it asserts TA as soon as it has driven valid data onto the bus. For a write cycle, it asserts TA as soon as it’s done with the data.
- Transfer Burst Inhibit/Transfer Cache Inhibit (TBI/TCI) This line is asserted at the same time as TA to indicate to the bus master that the cycle must not be cached, or that that the cycle can’t be completed as a burst transfer.

### 4.4 Electrical Specifications

### 4.4.1 Standard Signals

The majority of signals on the bus are in this group. These are the bussed signals, driven actively on the bus by F-series (or compatible) drivers, usually tri-stated when ownership of the signal changed for master and slave, and generally terminated with a 220Ω/330Ω thevenin terminator.

A0

-A31 | D0
-D31 | R/W
FC0

-FC2

6

### 4.4.2 Clock Signals

### 4.4.3 Open Collector Signals

Many of the bus signals are shared via open collector or open drain outputs rather than via tri-stated signals. A backplane resistor pulls these lines high, cards only drive the line low.

TA | TCI/TBI | TEA
RESET | R/W

### 4.4.4 Non-bussed signals

CFGINn | IRQn | R/W

CFGOUTn

### 4.4.5 Slot Power Availability

The system power for the expansion bus is based on the slot configurations. A backplane is always free to supply extra power, but it must meet the minimum requirements specified here. All cards must be designed with the minimum specifications in mind, especially the tolerances.

Pin | Supply
X, X | | +5 VDC ±5% @ 2A
X | | +12 VDC ±5% @ 500mA

7

### 4.5 Mechanical Specifications

### 4.6 Expansion Slot Pin Assignments

Table 1: Expansion Bus Connector Pinout

Pin | Name | Pin | Name | Pin | Name
a1 | NC¹ | b1 | D16 | c1 | NC
a2 | NC | b2 | D17 | c2 | NC
a3 | D0 | b3 | D18 | c3 | NC
a4 | D2 | b4 | D19 | c4 | NC
a5 | D4 | b5 | D20 | c5 | NC
a6 | D6 | b6 | D21 | c6 | NC
a7 | D8 | b7 | D22 | c7 | NC
a8 | D10 | b8 | D23 | c8 | NC
a9 | D12 | b9 | D24 | c9 | NC
a10 | D14 | b10 | D25 | c10 | NC
a11 | GND | b11 | D26 | c11 | NC
a12 | A1 | b12 | D27 | c12 | NC
a13 | A3 | b13 | D28 | c13 | NC
a14 | A5 | b14 | D29 | c14 | NC
a15 | A7 | b15 | D30 | c15 | NC
a16 | A9 | b16 | D31 | c16 | NC
a17 | A11 | b17 | A0 | c17 | NC
a18 | A13 | b18 | A0 | c18 | NC
a19 | A15 | b19 | NC | c19 | NC
a20 | A17 | b20 | NC | c20 | NC
a21 | A19 | b21 | NC | c21 | NC
a22 | NC | b22 | NC | c22 | NC
a23 | NC | b23 | NC | c23 | NC
a24 | NC | b24 | NC | c24 | NC
a25 | NC | b25 | NC | c25 | NC
a26 | NC | b26 | NC | c26 | NC
a27 | NC | b27 | NC | c27 | NC
a28 | NC | b28 | NC | c28 | NC
a29 | NC | b29 | NC | c29 | NC
a30 | NC | b30 | NC | c30 | NC
a31 | NC | b31 | NC | c31 | NC
a32 | NC | b32 | NC | c32 | NC
1 This means it’s not connected. You knew that though. This footnote is only here so I remember how to do it later.

8

## 5 Interrupt System

## 6 Special Thanks

Ben Eater for creating engaging videos on computer engineering, inspiring me to build a computer of my own.
Lawrence Manning MAXI030
Stephen Moody Y Ddraig(030)
Dave Haynie Author of “The Zorro III Bus Specification”

9

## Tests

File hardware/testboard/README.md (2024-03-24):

# Errata

* MC68150's TA line is *not* open-collector! Another 74LVC1G08 AND gate should
be used to connect FPGA TA and MC68150 TA to the CPU's TA.

* U802A schematic pin markings are incorrect. At the FPGA, the following changes
need to be made:
    - LV\_SIZ1 -> R/W
    - LV\_SIZ0 -> LV\_SIZ0
    - R/W -> LV\_SIZ1

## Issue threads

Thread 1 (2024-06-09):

[Feature Requests] - OS Support, Prototype boards, ISA slots... PCI?

Oichkatzelesfrettschen, 2024-06-09:
In 2024 it seems there are many enthusiasts who would love a computer like this. Tindie is one way to go, but there are many other sales outlets.

Operating systems could be:

- Linux/m68K (a lil crusty)
- NetBSD
- Chaotix
- G-DOS
- Keyronex
- DOSIX
- EMUTOS
- AROS

Some maybes:

- Xinu68K
- SysV-Src-68K
- RetroBSD
- gloworm
- FUSIX (dev contact needed)

Try to reach out to ActionRetro on YouTube, and to NCommander on YouTube (who also has a Discord server) to look into helping promote it more also!

Also would love to use various ISA and PCI graphics cards, Ethernet cards, and more with this! Especially the ones on Tindie

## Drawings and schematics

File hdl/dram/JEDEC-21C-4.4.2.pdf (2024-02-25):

### JEDEC Standard No. 21–C Page 4.4.2–1

### Release 6–7

NOTE: The 72 pin module standards that follow describe two separate devices. Both have a 4 byte data interface. One is intended to be used with or without parity bits while the other contains error correction bits ECC). The one with ECC is similar to the parity module but is not completely pin

### compatible

## 4.4.2 – 72 PIN SIMM DRAM MODULE FAMILY

### CAPACITY––256K TO 512M WORDS OF 32 or 36 BITS CONFIGURATION––SINGLE OR DOUBLE SIDED MODULES ––USING 1M, 4M, 16M. 64M, or 256M MEMORY DEVICES LOGIC FEATURES, These modules contain a “presence detect” feature which conists of output

pins which supply an encoded value which defines the storage capacity and speed of the module.

### PACKAGE––72 PIN SIMM MODULE PIN ASSIGNMENTS––Fig. 4.4.2–2A BLOCK DIAGRAMS––Fig. 4.4.2–2 AK. A series of block diagrams for recommended configurations is summarized in Fig 4.4.2–1 and detailed in Figs. 4.4.2–2 BK POWER & INTERFACE VOLTAGE LEVELS: A pinout is provided for 5.0 V and for 3.3 V power and

interface levels as defined by a voltage key in the socket.

## – 72 PIN SIMM DRAM ECC MODULE FAMILY

### CAPACITY––256K TO 512M WORDS OF 36 or 39 BITS CONFIGURATION––SINGLE OR DOUBLE SIDED MODULES ––USING 1M, 4M, 16M. 64M, or 256M MEMORY DEVICES

LOGIC FEATURES, These modules are optimized for ECC applications. They are similar to but not the same as the modules described in Fig. 4–6. The Standard defines a “presence detect” feature which consists of output pins which supply an encoded value which defines the storage capacity and speed of the module. The PD code identifies the presence of an ECC module as well as the speed and organization of the module. The Standard also defines the logic organization of the modules in Figs. 4.4.2–3B & 4.4.2–3C.

### PACKAGE––72 PIN SIMM MODULE PIN ASSIGNMENTS––Fig. 4.4.2–3A

BLOCK DIAGRAMS––Figs. 4.4.2–3 B & C. A series of block diagrams for recommended configura-

### tions is summarized in Fig 4.4.2–1 and detailed in Figs. 4.4.2–3 B & C POWER & INTERFACE VOLTAGE LEVELS: A pinout is provided for 5.0 V and for 3.3 V power and

interface levels as defined by a voltage key in the socket.

### Downloaded by Anthony Guerrero (anthony@anthony.moe) on Oct 23, 2023, 12:07 pm PDT

# anthonydotmoe

### Page 4.4.2–2

### Release 6–7

# 72 Pin SIMM Block Diagrams

The block diagrams given in the 12 pages, Figs 4.4.2–2 B K and Figs 4.4.2–3 B & C), are applicable to the 72 Pin SIMM pinouts shown in Figures 4.4.2–2 A and 4.4.2–3 A.

## These block diagrams are provided for guidance only. Other implementations with dif-

ferent block configurations are also acceptable.
The following table shows the applicability of the block configurations given to the 5 V and 3.3 V Non–ECC and ECC modules.
Configuration | # Banks | Applies to: 5 V SIMM

## Applies to: 3.3 V SIMM Parity, Non–Parity

X32/36 W/X4, X1 (X36) | 1 or 2 | X | X
X32/36 W/X16, X18 | 1 or 2 | X | X
X36 W/X4, X4/4CE | 1 or 2 | X | X
X36 W/X4, X2/2CE | 1 or 2 | X | X
X36 W/X16, X4/4CE | 1 or 2 | X | X
X36 W/X16, X2/2CE | 1 or 2 | X | X
X32 W/X8 | 1 or 2 | | X
X36 W/X8, X2/2CE | 1 or 2 | | X
X32 W/X32 | 1 or 2 | | X
X36 W/X32, X2/2CE | 1 or 2 | | X

## ECC

X36/40 W/X4 | 1 or 2 | X | X (X36 only)

## Note: To reduce the number of diagrams, only 2 bank versions are shown. In addition, in cases where one SIMM I/O width can

be described as a depopulation of another SIMM (i.e. X36X32),
the depopulated devices are shown by a ”dashed” outline.

RE AND G WIRING FOR BYTE WRITE SIMMS.
SIGNAL NAME | 5 V SIMMs | 3.3 V SIMMs
G | Tied to GND | Wired to Pin 46
RE0 | Connected as shown. Tied to pin 44 (RE0) | RE0, RE2 nets connected to-gether and tied to pin 44 (RE0)
RE1 | Connected as shown. Tied to pin 45 (RE1) | RE1, RE3 nets connected to-gether and tied to pin 45 (RE1)
RE2 | Connected as shown. Tied to pin 34 (RE2) | RE0, RE2 nets connected to-gether and tied to pin 44 (RE0)
RE3 | Connected as shown. Tied to pin 33 (RE3) | RE1, RE3 nets connected to-gether and tied to pin 45 (RE1)

# FIGURE 4.4.2–1 72 PIN DRAM SIMM APPLICABILITY TABLE

# anthonydotmoe
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

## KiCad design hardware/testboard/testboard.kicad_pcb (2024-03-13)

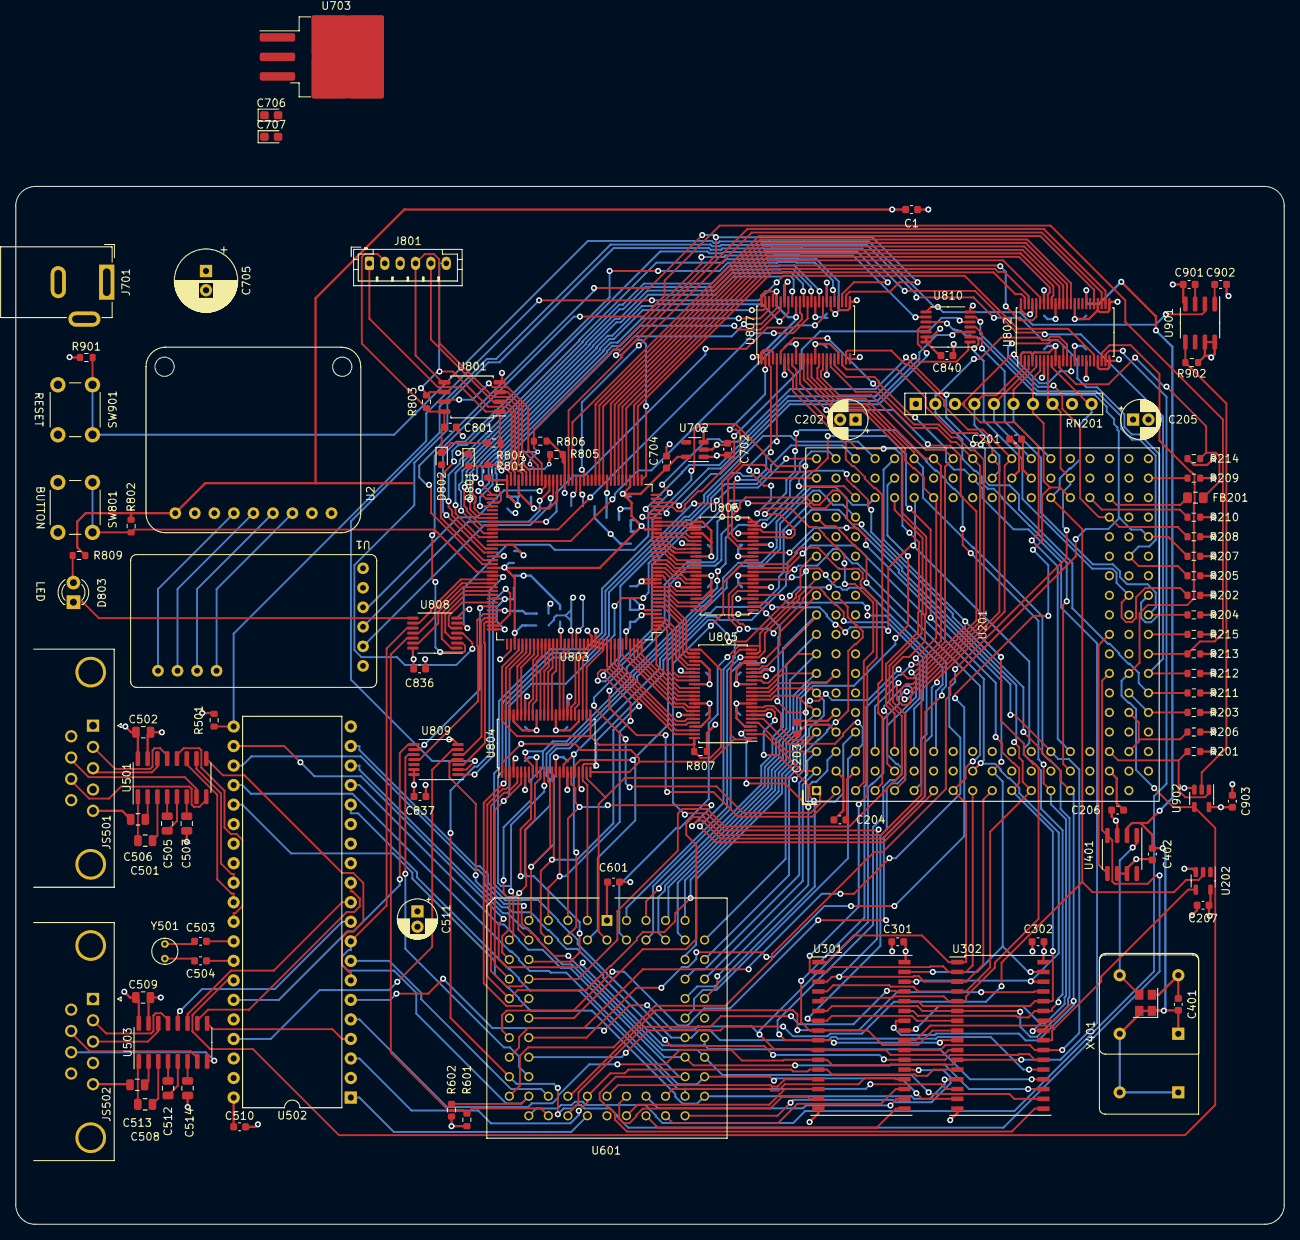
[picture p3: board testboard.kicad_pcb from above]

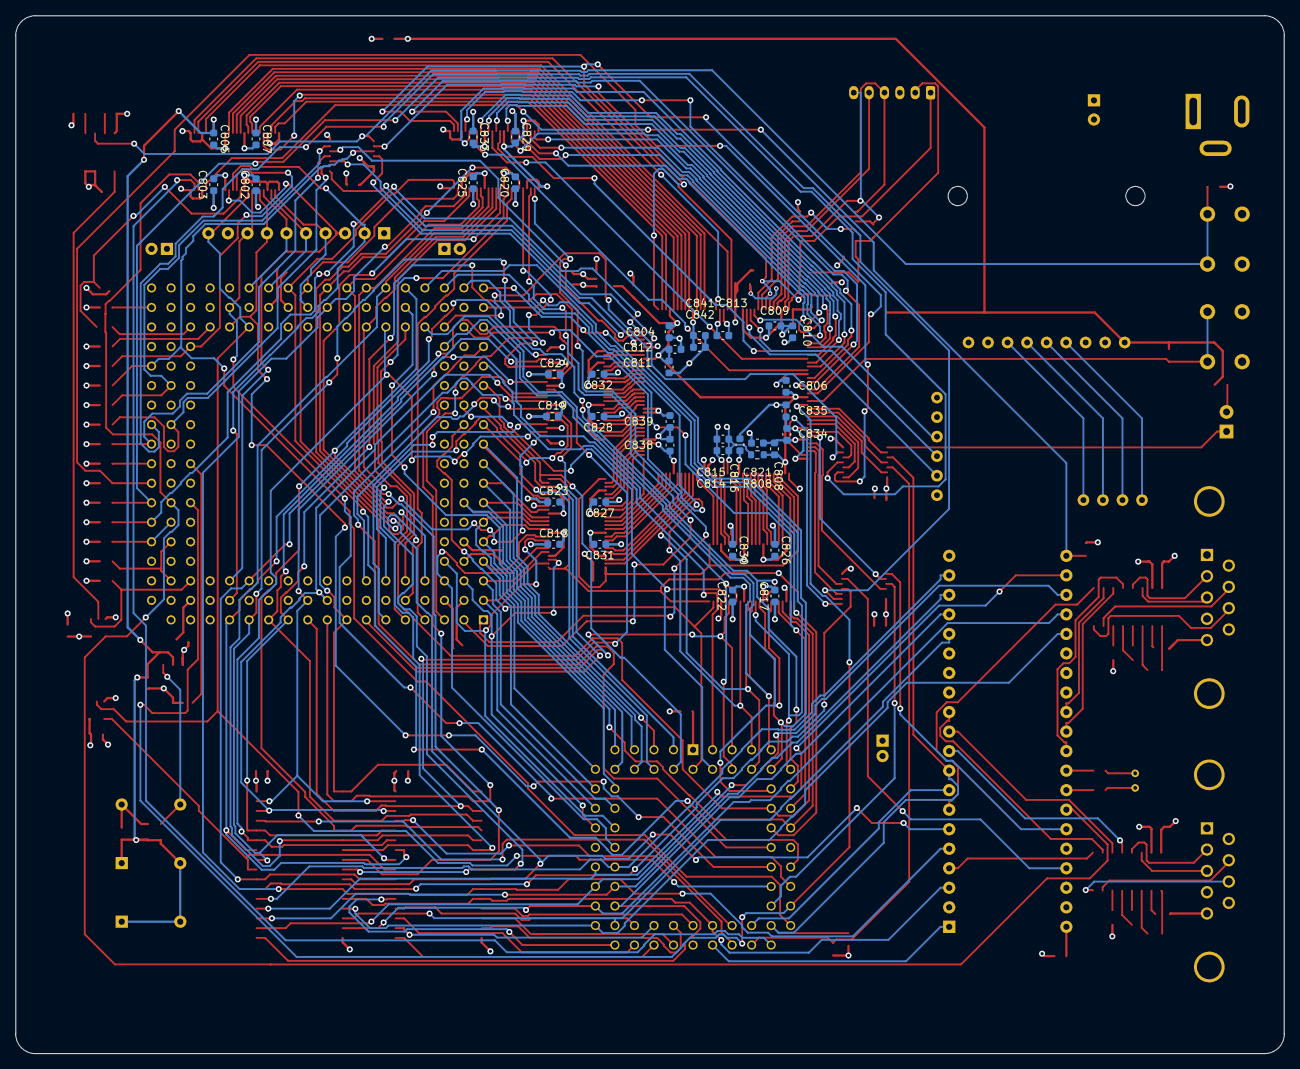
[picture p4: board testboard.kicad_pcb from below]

Board: 4 copper layers, 165.0 x 135.0 mm, 146 parts (39 on the bottom side), 278 nets.

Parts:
C1, C702, C704, C809, C812, C815, C821, C835, C839, C842: 4.7uF; C_0603_1608Metric
C201, C204: 0.22uF; C_0603_1608Metric
C202, C205: 22uF; CP_Radial_D5.0mm_P2.00mm
C203, C206: 220pF; C_0603_1608Metric
C207, C301, C302, C401, C402, C510, C601, C801, C802, C803, C804, C805, C806, C807, C808, C810, C811, C813, C814, C816, C817, C818, C819, C820, C822, C823, C824, C825, C826, C827, C828, C829, C830, C831, C832, C833, C834, C836, C837, C838, C840, C841, C901, C902, C903: 100nF; C_0603_1608Metric
C501, C502, C505, C506, C507, C508, C509, C512, C513, C514: 1uF; C_0805_2012Metric
C503, C504: 15pF; C_0603_1608Metric
C511: C_Polarized_Small_US; CP_Radial_D5.0mm_P2.00mm
C705: 220uF; CP_Radial_D8.0mm_P2.50mm
C706: 22uF; CP_EIA-2012-12_Kemet-R
C707: 10uF; CP_EIA-2012-12_Kemet-R
D801: LTST-C191KGKT; LED_0603_1608Metric
D802: D_Schottky; D_0603_1608Metric
D803: LED; LED_D3.0mm
FB201: FerriteBead; L_0805_2012Metric_Pad1.15x1.40mm_HandSolder
J701: Barrel_Jack; BarrelJack_GCT_DCJ200-10-A_Horizontal
J801: Conn_01x06; JST_PH_B6B-PH-K_1x06_P2.00mm_Vertical
JS501, JS502: DE9_Plug_MountingHoles; DSUB-9_Male_Horizontal_P2.77x2.84mm_EdgePinOffset4.94mm_Hou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
R201, R202, R203, R204, R205, R206, R207, R208, R209, R210, R211, R212, R213, R214, R215: 4.7k; R_0603_1608Metric
R501, R601, R602, R802, R901, R902: 1k; R_0603_1608Metric
R801, R809: 2.2K; R_0603_1608Metric
R803, R804: 10K; R_0603_1608Metric
R805, R806: 10k; R_0603_1608Metric
R807: R_Small_US; R_0603_1608Metric
R808: 100; R_0603_1608Metric
RN201: 1k; R_Array_SIP10
SW801: BUTTON; SW_PUSH_6mm
SW901: RESET; SW_PUSH_6mm
U1: DACMOD
U2: MAX98306 Amp; AMP
U201: 68LC040; PGA179
U202: 74LVC1G04; SOT-23-5
U301, U302: IS61C5128AS-25TLI; TSOP-II-32_21.0x10.2mm_P1.27mm
U401: NB3N502; SOIC-8_3.9x4.9mm_P1.27mm
U501, U503: MAX232; SOIC-16_3.9x9.9mm_P1.27mm
U502: 68681; DIP-40_W15.24mm
U601: PLCC-68_THT-Socket
U702: AP2112K-1.2; SOT-23-5
U703: LT1084-3.3; TO-263-3_TabPin2
U801: SST26VF023BA; SOP-8_5.28x5.23mm_P1.27mm
U802, U804, U805, U806, U807: SN74ALVC164245; TSSOP-48_6.1x12.5mm_P0.5mm
U803: ICE40HX4K-TQ144; TQFP-144_20x20mm_P0.5mm
U808, U810: SN74LVC07; TSSOP-14_4.4x5mm_P0.65mm
U809: 74AHCT04; TSSOP-14_4.4x5mm_P0.65mm
U901: TL7705A; SOIC-8_3.9x4.9mm_P1.27mm
U902: 74LVC1G08; SOT-23-5
X401: ASE-33MHz; Oscillator_SMD_Abracon_ASE-4Pin_3.2x2.5mm
X402: 33MHz; Oscillator_DIP-14
X403: 33MHz; Oscillator_DIP-8
Y501: 3.6864MHz; Crystal_C38-LF_D3.0mm_L8.0mm_Vertical

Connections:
+1V2: C704.1, C804.1, C806.1, C808.1, C811.1, C812.1, R808.2, U702.5 (VOUT), U803.27 (VCC), U803.40 (VCC), U803.92 (VCC), U803.111 (VCC)
+3.3V: C1.1, C401.1, C402.1, C706.1, C805.1, C807.1, C809.1, C810.1, C816.1, C821.1, C826.1, C827.1, C828.1, C829.1, C830.1, C831.1, C832.1, C833.1, C834.1, C835.1, C836.1, C838.1, C839.1, C840.1, C841.1, C842.1, D802.2 (A), R801.2, R802.1, R805.1, R806.1, R807.1, R809.2, U1.1 (VIN), U2.1 (V_{DD}), U401.2 (VDD), U703.2 (VO), U802.31 (VCCA), U802.42 (VCCA), U803.6 (VCCIO_3), U803.30 (VCCIO_3), U803.46 (VCCIO_2), U803.57 (VCCIO_2), U803.72 (VCC_SPI), U803.89 (VCCIO_1), U803.100 (VCCIO_1), U803.108 (VPP_2V5), U803.123 (VCCIO_0), U803.131 (VCCIO_0), U804.31 (VCCA), U804.42 (VCCA), U805.31 (VCCA), U805.42 (VCCA), U806.31 (VCCA), U806.42 (VCCA), U807.31 (VCCA), U807.42 (VCCA), U808.14 (VCC), U810.13, U810.14 (VCC), X401.1 (EN), X401.4 (Vdd), X402.1 (EN), X402.14 (Vcc), X403.1 (EN), X403.8 (Vcc)
+5V: C201.1, C202.1, C203.1, C204.1, C205.1, C206.1, C207.1, C301.1, C302.1, C502.1, C509.1, C510.1, C511.1, C601.1, C702.1, C705.1, C707.1, C802.1, C803.1, C817.1, C818.1, C819.1, C820.1, C822.1, C823.1, C824.1, C825.1, C837.1, C903.1, J701.1, R201.1, R202.1, R203.1, R204.1, R205.1, R206.1, R207.1, R208.1, R209.1, R210.1, R211.1, R212.1, R213.1, R214.1, R215.1, R501.1, R601.1, R602.1, R901.1, R902.1, RN201.1 (common), U201.B5 (V_{CC}), U201.B9 (V_{CC}), U201.B14 (V_{CC}), U201.C2 (V_{CC}), U201.C5 (V_{CC}), U201.C8 (V_{CC}), U201.C10 (V_{CC}), U201.C12 (V_{CC}), U201.C14 (V_{CC}), U201.C17 (V_{CC}), U201.G2 (V_{CC}), U201.G17 (V_{CC}), U201.H3 (V_{CC}), U201.H16 (V_{CC}), U201.J3 (V_{CC}), U201.J16 (V_{CC}), U201.L16 (V_{CC}), U201.M2 (V_{CC}), U201.M3 (V_{CC}), U201.M17 (V_{CC}), U201.R2 (V_{CC}), U201.R5 (V_{CC}), U201.R8 (V_{CC}), U201.R12 (V_{CC}), U201.R17 (V_{CC}), U201.S8 (V_{CC}), U201.S16 (V_{CC}), U202.5 (VCC), U301.32 (VDD), U302.32 (VDD), U501.16 (VCC), U502.40 (VCC), U503.16 (VCC), U601.1 (V_{CC}), U601.35 (V_{CC}), U702.1 (VIN), U702.3 (EN), U703.3 (VI), U802.7 (VCCB), U802.18 (VCCB), U804.7 (VCCB), U804.18 (VCCB), U805.7 (VCCB), U805.18 (VCCB), U806.7 (VCCB), U806.18 (VCCB), U807.7 (VCCB), U807.18 (VCCB), U809.13, U809.14 (VCC), U901.7 (SENSE), U901.8 (VCC), U902.5 (VCC)
/A0: U201.L18 (A0), U601.20 (A0), U807.23 (2B8)
/A1: U201.K18 (A1), U601.19 (A1), U807.22 (2B7)
/A2: U201.J17 (A2), U301.11 (A1), U302.11 (A1), U502.5 (RS3), U807.20 (2B6)
/A3: U201.J18 (A3), U301.10 (A2), U302.10 (A2), U502.6 (RS4), U807.19 (2B5)
/A4: U201.H18 (A4), U301.9 (A3), U302.9 (A3), U807.17 (2B4)
/A5: U201.G18 (A5), U301.8 (A4), U302.8 (A4), U807.16 (2B3)
/A6: U201.G16 (A6), U301.7 (A5), U302.7 (A5), U807.13 (2B1)
/A7: U201.F18 (A7), U301.6 (A6), U302.6 (A6), U807.14 (2B2)
/A8: U201.E18 (A8), U301.5 (A7), U302.5 (A7), U806.2 (1B1)
/A9: U201.F16 (A9), U301.27 (A8), U302.27 (A8), U806.3 (1B2)
/A10: U201.P1 (A10), U301.26 (A9), U302.26 (A9), U806.23 (2B8)
/A11: U201.N3 (A11), U301.23 (A10), U302.23 (A10), U806.22 (2B7)
/A12: U201.N1 (A12), U301.25 (A11), U302.25 (A11), U806.20 (2B6)
/A13: U201.M1 (A13), U301.4 (A12), U302.4 (A12), U806.19 (2B5)
/A14: U201.L1 (A14), U301.28 (A13), U302.28 (A13), U806.17 (2B4)
/A15: U201.K1 (A15), U301.3 (A14), U302.3 (A14), U806.14 (2B2)
/A16: U201.K2 (A16), U301.31 (A15), U302.31 (A15), U806.16 (2B3)
/A17: U201.J1 (A17), U301.2 (A16), U302.2 (A16), U806.13 (2B1)
/A18: U201.H1 (A18), U301.1 (A17), U302.1 (A17), U806.11 (1B7)
/A19: U201.J2 (A19), U301.30 (A18), U302.30 (A18), U806.12 (1B8)
/A20: U201.G1 (A20), U806.8 (1B5)
/A21: U201.F1 (A21), U806.5 (1B3)
/A22: U201.E1 (A22), U807.12 (1B8)
/A23: U201.G3 (A23), U806.9 (1B6)
/A24: U201.D1 (A24), U807.8 (1B5)
/A25: U201.F3 (A25), U806.6 (1B4)
/A26: U201.E2 (A26), U807.11 (1B7)
/A27: U201.C1 (A27), U807.5 (1B3)
/A28: U201.E3 (A28), U807.9 (1B6)
/A29: U201.B1 (A29), U807.3 (1B2)
/A30: U201.D3 (A30), U807.6 (1B4)
/A31: U201.A1 (A31), U807.2 (1B1)
/BCLK: U201.R7 (BCLK), U401.4 (REF), U601.24 (BCLK), U803.94 (IOR_141_GBIN2)
/CPU/DLE: R215.2, U201.T9 (JS0)
/CPU/PCLK: U201.R9 (PCLK), U401.5 (CLKOUT)
/CPU/~BB: R209.2, U201.T17 (~BB)
/CPU/~MI: R210.2, U201.Q16 (~MI)
/Clock/CLK33: U401.1 (X1/CLK), X401.3 (OUT), X403.5 (OUT)
/D0: U201.C3 (D0), U601.53 (D0), U805.6 (1B4)
/D1: U201.B3 (D1), U601.54 (D1), U805.3 (1B2)
/D2: U201.C4 (D2), U601.55 (D2), U805.8 (1B5)
/D3: U201.A2 (D3), U601.56 (D3), U805.2 (1B1)
/D4: U201.A3 (D4), U601.57 (D4), U805.5 (1B3)
/D5: U201.A4 (D5), U601.58 (D5), U805.9 (1B6)
/D6: U201.A5 (D6), U601.59 (D6), U805.11 (1B7)
/D7: U201.A6 (D7), U601.60 (D7), U805.12 (1B8)
/D8: U201.B7 (D8), U601.61 (D8), U805.13 (2B1)
/D9: U201.A7 (D9), U601.62 (D9), U805.14 (2B2)
/D10: U201.A8 (D10), U601.63 (D10), U805.16 (2B3)
/D11: U201.A9 (D11), U601.64 (D11), U805.17 (2B4)
/D12: U201.A10 (D12), U601.65 (D12), U805.19 (2B5)
/D13: U201.A11 (D13), U601.66 (D13), U805.20 (2B6)
/D14: U201.A12 (D14), U601.67 (D14), U805.22 (2B7)
/D15: U201.A13 (D15), U601.68 (D15), U805.23 (2B8)
/D16: U201.B11 (D16), U601.2 (D16), U804.23 (2B8)
/D17: U201.A14 (D17), U601.3 (D17), U804.22 (2B7)
/D18: U201.B12 (D18), U601.4 (D18), U804.20 (2B6)
/D19: U201.A15 (D19), U601.5 (D19), U804.19 (2B5)
/D20: U201.A16 (D20), U601.6 (D20), U804.17 (2B4)
/D21: U201.A17 (D21), U601.7 (D21), U804.16 (2B3)
/D22: U201.B16 (D22), U601.8 (D22), U804.14 (2B2)
/D23: U201.C15 (D23), U601.9 (D23), U804.13 (2B1)
/D24: U201.A18 (D24), U601.10 (D24), U804.12 (1B8)
/D25: U201.C16 (D25), U601.11 (D25), U804.11 (1B7)
/D26: U201.B18 (D26), U601.12 (D26), U804.9 (1B6)
/D27: U201.D16 (D27), U601.13 (D27), U804.8 (1B5)
/D28: U201.C18 (D28), U601.14 (D28), U804.6 (1B4)
/D29: U201.E16 (D29), U601.15 (D29), U804.5 (1B3)
/D30: U201.E17 (D30), U601.16 (D30), U804.3 (1B2)
/D31: U201.D18 (D31), U601.17 (D31), U804.2 (1B1)
/FPGA/CDONE: D801.2 (A), R801.1, R806.2, U803.65 (CDONE), U810.9
/FPGA/FLASH_IO2: U801.3 (~WP/SIO2), U803.64 (IOB_104_CBSEL1)
/FPGA/FLASH_IO3: U801.7 (~HOLD/SIO3), U803.63 (IOB_103_CBSEL0)
/FPGA/FLASH_MISO: J801.5, U801.2 (SO/SIO1), U803.68 (IOB_106_SDI)
/FPGA/FLASH_MOSI: J801.4, U801.5 (SI/SIO0), U803.67 (IOB_105_SDO)
/FPGA/FLASH_POWER: C801.1, D802.1 (K), J801.2, R803.2, R804.2, U801.8 (VCC)
/FPGA/FLASH_SCK: J801.6, R803.1, U801.6 (SCLK), U803.70 (IOB_107_SCK)
/FPGA/FLASH_SS: J801.1, R804.1, U801.1 (~CS), U803.71 (IOB_108_SS)
/FPGA/FPGA_BTN: R802.2, SW801.2, U803.93 (IOR_140_GBIN3)
/FPGA/FPGA_D_DIR: U803.110 (IOT_168), U804.1 (1DIR), U804.24 (2DIR), U805.1 (1DIR), U805.24 (2DIR)
/FPGA/FPGA_D_~OE: R807.2, U803.112 (IOT_169), U804.25 (*2OE), U804.48 (*1OE), U805.25 (*2OE), U805.48 (*1OE)
/FPGA/FPGA_LED: U803.95 (IOR_144), U808.9
/FPGA/GND_PLL: C813.2, C814.2, C815.2, U803.53 (GNDPLL0), U803.127 (GNDPLL1)
/FPGA/LV.A0: U803.37 (IOB_56), U803.91 (IOR_139), U807.26 (2A8)
/FPGA/LV.A1: U803.90 (IOR_138), U807.27 (2A7)
/FPGA/LV.A2: U803.88 (IOR_137), U807.29 (2A6)
/FPGA/LV.A3: U803.87 (IOR_136), U807.30 (2A5)
/FPGA/LV.A4: U803.85 (IOR_128), U807.32 (2A4)
/FPGA/LV.A5: U803.84 (IOR_120), U807.33 (2A3)
/FPGA/LV.A6: U803.82 (IOR_118), U807.36 (2A1)
/FPGA/LV.A7: U803.83 (IOR_119), U807.35 (2A2)
/FPGA/LV.A8: U803.10 (IOL_5B), U806.47 (1A1)
/FPGA/LV.A9: U803.11 (IOL_8A), U806.46 (1A2)
/FPGA/LV.A10: U803.29 (IOL_23B), U806.26 (2A8)
/FPGA/LV.A11: U803.28 (IOL_23A), U806.27 (2A7)
/FPGA/LV.A12: U803.26 (IOL_18B), U806.29 (2A6)
/FPGA/LV.A13: U803.25 (IOL_18A), U806.30 (2A5)
/FPGA/LV.A14: U803.24 (IOL_17B), U806.32 (2A4)
/FPGA/LV.A15: U803.22 (IOL_14B), U806.35 (2A2)
/FPGA/LV.A16: U803.23 (IOL_17A), U806.33 (2A3)
/FPGA/LV.A17: U803.21 (IOL_14A_GBIN6), U806.36 (2A1)
/FPGA/LV.A18: U803.18 (IOL_12B), U806.38 (1A7)
/FPGA/LV.A19: U803.19 (IOL_13A), U806.37 (1A8)
/FPGA/LV.A20: U803.16 (IOL_10B), U806.41 (1A5)
/FPGA/LV.A21: U803.12 (IOL_8B), U806.44 (1A3)
/FPGA/LV.A22: U803.81 (IOR_117), U807.37 (1A8)
/FPGA/LV.A23: U803.17 (IOL_12A), U806.40 (1A6)
/FPGA/LV.A24: U803.78 (IOR_114), U807.41 (1A5)
/FPGA/LV.A25: U803.15 (IOL_10A), U806.43 (1A4)
/FPGA/LV.A26: U803.80 (IOR_116), U807.38 (1A7)
/FPGA/LV.A27: U803.75 (IOR_111), U807.44 (1A3)
/FPGA/LV.A28: U803.79 (IOR_115), U807.40 (1A6)
/FPGA/LV.A29: U803.74 (IOR_110), U807.46 (1A2)
/FPGA/LV.A30: U803.76 (IOR_112), U807.43 (1A4)
/FPGA/LV.A31: U803.73 (IOR_109), U807.47 (1A1)
/FPGA/LV_68150_CS: U803.104 (IOR_164), U809.11
/FPGA/LV_AVEC: U803.107 (IOR_167), U809.1
/FPGA/LV_COM_CS: U803.102 (IOR_161), U809.9
/FPGA/LV_COM_IACK: U803.105 (IOR_165), U809.5
/FPGA/LV_D0: U803.138 (IOT_216), U805.43 (1A4)
/FPGA/LV_D1: U803.136 (IOT_214), U805.46 (1A2)
/FPGA/LV_D2: U803.139 (IOT_217), U805.41 (1A5)
/FPGA/LV_D3: U803.135 (IOT_213), U805.47 (1A1)
/FPGA/LV_D4: U803.137 (IOT_215), U805.44 (1A3)
/FPGA/LV_D5: U803.141 (IOT_219), U805.40 (1A6)
/FPGA/LV_D6: U803.142 (IOT_220), U805.38 (1A7)
/FPGA/LV_D7: U803.143 (IOT_221), U805.37 (1A8)
/FPGA/LV_D8: U803.144 (IOT_222), U805.36 (2A1)
/FPGA/LV_D9: U803.1 (IOL_2A), U805.35 (2A2)
/FPGA/LV_D10: U803.2 (IOL_2B), U805.33 (2A3)
/FPGA/LV_D11: U803.3 (IOL_3A), U805.32 (2A4)
/FPGA/LV_D12: U803.4 (IOL_3B), U805.30 (2A5)
/FPGA/LV_D13: U803.7 (IOL_4A), U805.29 (2A6)
/FPGA/LV_D14: U803.8 (IOL_4B), U805.27 (2A7)
/FPGA/LV_D15: U803.9 (IOL_5A), U805.26 (2A8)
/FPGA/LV_D16: U803.134 (IOT_212), U804.26 (2A8)
/FPGA/LV_D17: U803.130 (IOT_206), U804.27 (2A7)
/FPGA/LV_D18: U803.129 (IOT_198_GBIN0), U804.29 (2A6)
/FPGA/LV_D19: U803.128 (IOT_197_GBIN1), U804.30 (2A5)
/FPGA/LV_D20: U803.125 (IOT_192), U804.32 (2A4)
/FPGA/LV_D21: U803.124 (IOT_191), U804.33 (2A3)
/FPGA/LV_D22: U803.122 (IOT_190), U804.35 (2A2)
/FPGA/LV_D23: U803.121 (IOT_181), U804.36 (2A1)
/FPGA/LV_D24: U803.120 (IOT_179), U804.37 (1A8)
/FPGA/LV_D25: U803.119 (IOT_178), U804.38 (1A7)
/FPGA/LV_D26: U803.118 (IOT_177), U804.40 (1A6)
/FPGA/LV_D27: U803.117 (IOT_174), U804.41 (1A5)
/FPGA/LV_D28: U803.116 (IOT_173), U804.43 (1A4)
/FPGA/LV_D29: U803.115 (IOT_172), U804.44 (1A3)
/FPGA/LV_D30: U803.114 (IOT_171), U804.46 (1A2)
/FPGA/LV_D31: U803.113 (IOT_170), U804.47 (1A1)
/FPGA/LV_RAM_CS: U803.106 (IOR_166), U809.3
/FPGA/LV_R/~W: U802.43 (1A4), U803.42 (IOB_64)
/FPGA/LV_SIZ0: U802.41 (1A5), U803.43 (IOB_71)
/FPGA/LV_SIZ1: U802.40 (1A6), U803.44 (IOB_72)
/FPGA/LV_TM0: U802.44 (1A3), U803.41 (IOB_63)
/FPGA/LV_TM1: U802.46 (1A2), U803.39 (IOB_61)
/FPGA/LV_TM2: U802.47 (1A1), U803.38 (IOB_57)
/FPGA/LV_TT0: U802.35 (2A2), U803.49 (IOB_81_GBIN5)
/FPGA/LV_TT1: U802.36 (2A1), U803.48 (IOB_80)
/FPGA/LV_~68150_DS: U802.26 (2A8), U803.56 (IOB_94)
/FPGA/LV_~COM_IRQ: U802.29 (2A6), U803.55 (IOB_91)
/FPGA/LV_~DSACK0: U803.96 (IOR_146), U808.11
/FPGA/LV_~DSACK1: U803.97 (IOR_147), U808.13
/FPGA/LV_~IPL0: U803.98 (IOR_148), U808.1
/FPGA/LV_~IPL1: U803.99 (IOR_152), U808.3
/FPGA/LV_~IPL2: U803.101 (IOR_160), U808.5
/FPGA/LV_~RST: U802.27 (2A7), U803.52 (IOB_82_GBIN4)
/FPGA/LV_~TA: U803.34 (IOL_25B), U810.11
/FPGA/LV_~TBI: U803.31 (IOL_24A), U810.1
/FPGA/LV_~TCI: U803.32 (IOL_24B), U810.3
/FPGA/LV_~TEA: U803.33 (IOL_25A), U810.5
/FPGA/LV_~TIP: U802.37 (1A8), U803.47 (IOB_79)
/FPGA/LV_~TS: U802.38 (1A7), U803.45 (IOB_73)
/FPGA/SND_BCLK: U1.5 (BCK), U803.60 (IOB_95)
/FPGA/SND_DOUT: U1.4 (DIN), U803.61 (IOB_96)
/FPGA/SND_LRCLK: U1.3 (LRCLK), U803.62 (IOB_102)
/FPGA/VCC_PLL: C813.1, C814.1, C815.1, R808.1, U803.54 (VCCPLL0), U803.126 (VCCPLL1)
/IO/A_RX: U501.12 (R1OUT), U502.31 (RXDA)
/IO/A_TX: U501.11 (T1IN), U502.30 (TXDA)
/IO/A_~CTS: U501.9 (R2OUT), U502.7 (IP0)
/IO/A_~RTS: U501.10 (T2IN), U502.29 (OP0)
/IO/B_RX: U502.10 (RXDB), U503.12 (R1OUT)
/IO/B_TX: U502.11 (TXDB), U503.11 (T1IN)
/IO/B_~CTS: U502.4 (IP1), U503.9 (R2OUT)
/IO/B_~RTS: U502.12 (OP1), U503.10 (T2IN)
/IO/COM1_CTS: JS501.8, U501.8 (R2IN)
/IO/COM1_RTS: JS501.7, U501.7 (T2OUT)
/IO/COM1_RXD: JS501.2, U501.13 (R1IN)
/IO/COM1_TXD: JS501.3, U501.14 (T1OUT)
/IO/COM2_CTS: JS502.8, U503.8 (R2IN)
/IO/COM2_RTS: JS502.7, U503.7 (T2OUT)
/IO/COM2_RXD: JS502.2, U503.13 (R1IN)
/IO/COM2_TXD: JS502.3, U503.14 (T1OUT)
/PA0: U502.1 (RS1), U601.33 (PA0)
/PA1: U301.12 (A0), U302.12 (A0), U502.3 (RS2), U601.34 (PA1)
/PD16: U301.13 (I/O0), U601.36 (PD16)
/PD17: U301.14 (I/O1), U601.37 (PD17)
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

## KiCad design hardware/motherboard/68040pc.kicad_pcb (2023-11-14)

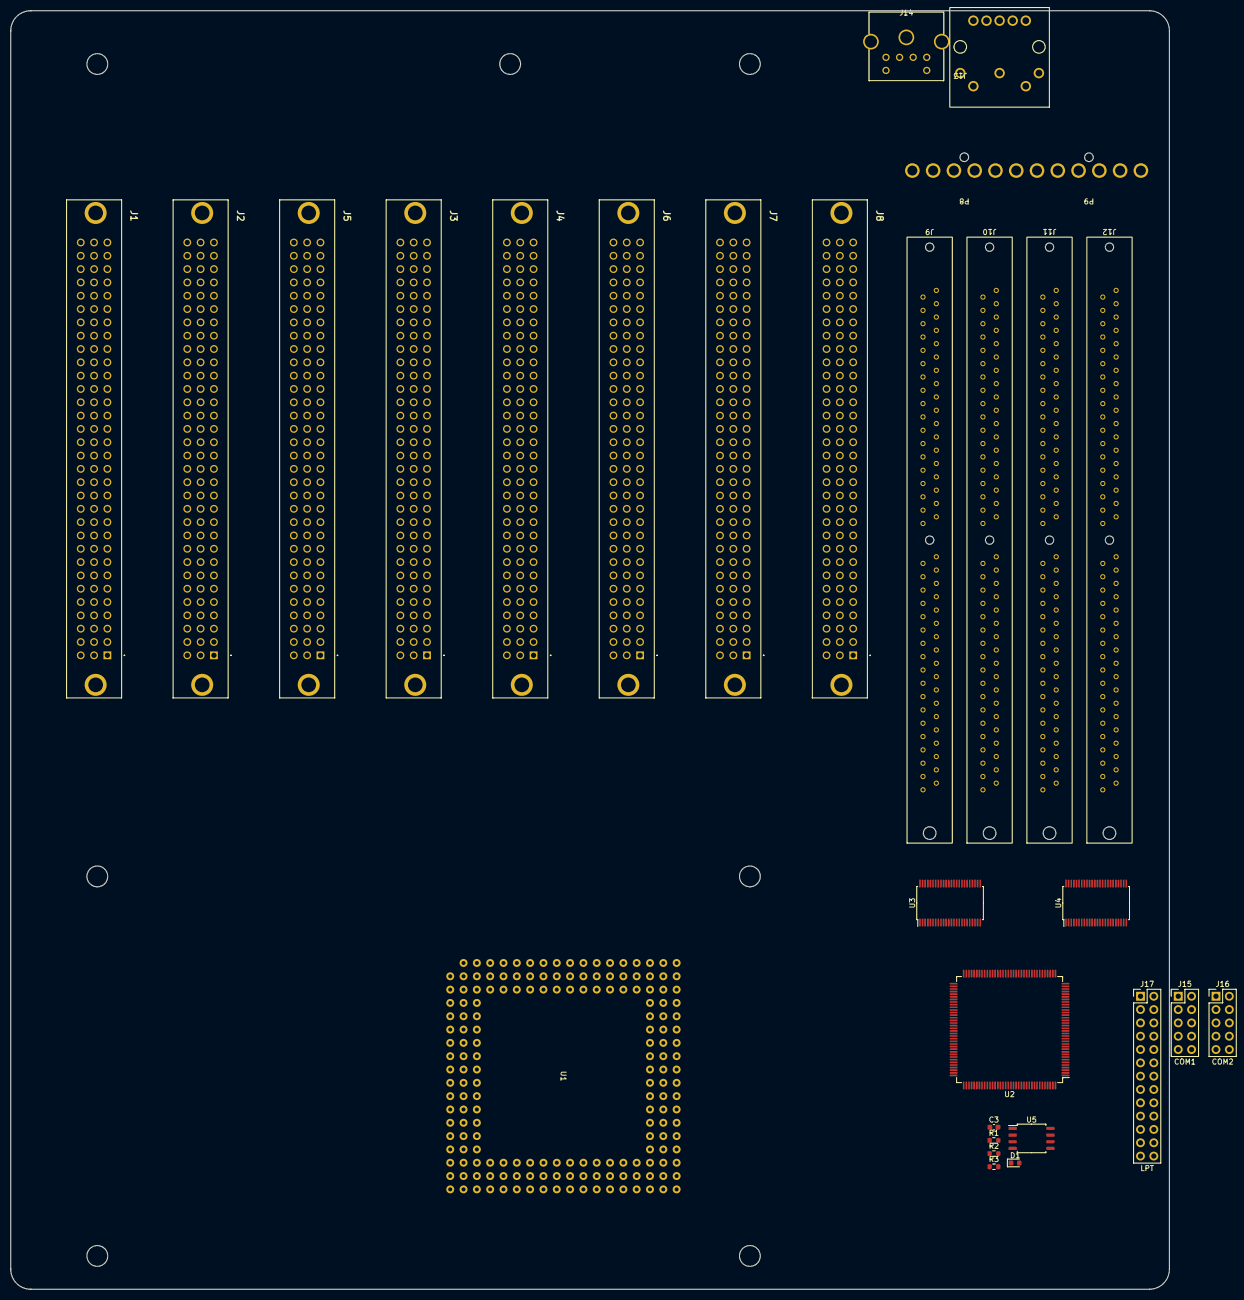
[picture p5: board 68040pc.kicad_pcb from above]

Board: 4 copper layers, 221.0 x 243.8 mm, 29 parts (0 on the bottom side), 135 nets, no tracks yet.

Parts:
C3: 0.1u; C_0603_1608Metric
D1: LTST-C191KGKT; LED_0603_1608Metric
J1, J2, J3, J4, J5, J6, J7, J8: EXP
J9, J10, J11, J12: SIMM-72
J13: DIN-5_180degree; DIN5-180
J14: Mini-DIN-6; Mini-DIN6
J15: COM1; PinHeader_2x05_P2.54mm_Vertical
J16: COM2; PinHeader_2x05_P2.54mm_Vertical
J17: LPT; PinHeader_2x13_P2.54mm_Vertical
P8, P9: Conn_01x06; 15-48-0106
R1: 2.2K; R_0603_1608Metric
R2, R3: 10K; R_0603_1608Metric
U1: 68LC040; PGA179
U2: ICE40HX4K-TQ144; TQFP-144_20x20mm_P0.5mm
U3, U4: SN74ALVC164245; TSSOP-48_6.1x12.5mm_P0.5mm
U5: W25Q32JVSSIM; SOIC-8_5.23x5.23mm_P1.27mm

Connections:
+3V3: C3.1, J9.10 (VCC), J9.30 (VCC), J9.59 (VCC), J10.10 (VCC), J10.30 (VCC), J10.59 (VCC), J11.10 (VCC), J11.30 (VCC), J11.59 (VCC), J12.10 (VCC), J12.30 (VCC), J12.59 (VCC), R1.2, R2.2, R3.2, U3.31 (VCCA), U3.42 (VCCA), U4.31 (VCCA), U4.42 (VCCA), U5.8 (VCC)
+5V: P8.2, P9.4, P9.5, P9.6, U3.7 (VCCB), U3.18 (VCCB), U4.7 (VCCB), U4.18 (VCCB)
/Expansion/A0: J1.B17, J2.B17, J3.B17, J4.B17, J5.B17, J6.B17, J7.B17, J8.B17, U1.L18 (A0), U2.88 (IOR_137)
/Expansion/A1: J1.A12, J2.A12, J3.A12, J4.A12, J5.A12, J6.A12, J7.A12, J8.A12, U1.K18 (A1), U2.90 (IOR_138)
/Expansion/A2: J1.C12, J2.C12, J3.C12, J4.C12, J5.C12, J6.C12, J7.C12, J8.C12, U1.J17 (A2), U2.91 (IOR_139)
/Expansion/A3: J1.A13, J2.A13, J3.A13, J4.A13, J5.A13, J6.A13, J7.A13, J8.A13, U1.J18 (A3), U2.93 (IOR_140_GBIN3)
/Expansion/A4: J1.C13, J2.C13, J3.C13, J4.C13, J5.C13, J6.C13, J7.C13, J8.C13, U1.H18 (A4), U2.94 (IOR_141_GBIN2)
/Expansion/A5: J1.A14, J2.A14, J3.A14, J4.A14, J5.A14, J6.A14, J7.A14, J8.A14, U1.G18 (A5), U2.95 (IOR_144)
/Expansion/A6: J1.C14, J2.C14, J3.C14, J4.C14, J5.C14, J6.C14, J7.C14, J8.C14, U1.G16 (A6), U2.96 (IOR_146)
/Expansion/A7: J1.A15, J2.A15, J3.A15, J4.A15, J5.A15, J6.A15, J7.A15, J8.A15, U1.F18 (A7), U2.97 (IOR_147)
/Expansion/A8: J1.C15, J2.C15, J3.C15, J4.C15, J5.C15, J6.C15, J7.C15, J8.C15, U1.E18 (A8), U2.98 (IOR_148)
/Expansion/A9: J1.A16, J2.A16, J3.A16, J4.A16, J5.A16, J6.A16, J7.A16, J8.A16, U1.F16 (A9), U2.99 (IOR_152)
/Expansion/A10: J1.C16, J2.C16, J3.C16, J4.C16, J5.C16, J6.C16, J7.C16, J8.C16, U1.P1 (A10), U2.101 (IOR_160)
/Expansion/A11: J1.A17, J2.A17, J3.A17, J4.A17, J5.A17, J6.A17, J7.A17, J8.A17, U1.N3 (A11), U2.102 (IOR_161)
/Expansion/A12: J1.C17, J2.C17, J3.C17, J4.C17, J5.C17, J6.C17, J7.C17, J8.C17, U1.N1 (A12), U2.104 (IOR_164)
/Expansion/A13: J1.A18, J2.A18, J3.A18, J4.A18, J5.A18, J6.A18, J7.A18, J8.A18, U1.M1 (A13), U2.105 (IOR_165)
/Expansion/A14: J1.C18, J2.C18, J3.C18, J4.C18, J5.C18, J6.C18, J7.C18, J8.C18, U1.L1 (A14), U2.106 (IOR_166)
/Expansion/A15: J1.A19, J2.A19, J3.A19, J4.A19, J5.A19, J6.A19, J7.A19, J8.A19, U1.K1 (A15), U2.107 (IOR_167)
/Expansion/A16: J1.C19, J2.C19, J3.C19, J4.C19, J5.C19, J6.C19, J7.C19, J8.C19, U1.K2 (A16), U2.110 (IOT_168)
/Expansion/A17: J1.A20, J2.A20, J3.A20, J4.A20, J5.A20, J6.A20, J7.A20, J8.A20, U1.J1 (A17), U2.112 (IOT_169)
/Expansion/A18: J1.C20, J2.C20, J3.C20, J4.C20, J5.C20, J6.C20, J7.C20, J8.C20, U1.H1 (A18), U2.113 (IOT_170)
/Expansion/A19: J1.A21, J2.A21, J3.A21, J4.A21, J5.A21, J6.A21, J7.A21, J8.A21, U1.J2 (A19), U2.114 (IOT_171)
/Expansion/A20: J1.B18, J2.B18, J3.B18, J4.B18, J5.B18, J6.B18, J7.B18, J8.B18, U1.G1 (A20), U2.115 (IOT_172)
/Expansion/A21: J1.B19, J2.B19, J3.B19, J4.B19, J5.B19, J6.B19, J7.B19, J8.B19, U1.F1 (A21), U2.116 (IOT_173)
/Expansion/A22: J1.B20, J2.B20, J3.B20, J4.B20, J5.B20, J6.B20, J7.B20, J8.B20, U1.E1 (A22), U2.117 (IOT_174)
/Expansion/A23: J1.B21, J2.B21, J3.B21, J4.B21, J5.B21, J6.B21, J7.B21, J8.B21, U1.G3 (A23), U2.118 (IOT_177)
/Expansion/A24: J1.B22, J2.B22, J3.B22, J4.B22, J5.B22, J6.B22, J7.B22, J8.B22, U1.D1 (A24), U2.119 (IOT_178)
/Expansion/A25: J1.B23, J2.B23, J3.B23, J4.B23, J5.B23, J6.B23, J7.B23, J8.B23, U1.F3 (A25), U2.120 (IOT_179)
/Expansion/A26: J1.B24, J2.B24, J3.B24, J4.B24, J5.B24, J6.B24, J7.B24, J8.B24, U1.E2 (A26), U2.121 (IOT_181)
/Expansion/A27: J1.B25, J2.B25, J3.B25, J4.B25, J5.B25, J6.B25, J7.B25, J8.B25, U1.C1 (A27), U2.122 (IOT_190)
/Expansion/A28: J1.B26, J2.B26, J3.B26, J4.B26, J5.B26, J6.B26, J7.B26, J8.B26, U1.E3 (A28), U2.124 (IOT_191)
/Expansion/A29: J1.B27, J2.B27, J3.B27, J4.B27, J5.B27, J6.B27, J7.B27, J8.B27, U1.B1 (A29), U2.125 (IOT_192)
/Expansion/A30: J1.B28, J2.B28, J3.B28, J4.B28, J5.B28, J6.B28, J7.B28, J8.B28, U1.D3 (A30), U2.128 (IOT_197_GBIN1)
/Expansion/A31: J1.B29, J2.B29, J3.B29, J4.B29, J5.B29, J6.B29, J7.B29, J8.B29, U1.A1 (A31), U2.129 (IOT_198_GBIN0)
/Expansion/D0: J1.A3, J2.A3, J3.A3, J4.A3, J5.A3, J6.A3, J7.A3, J8.A3, U1.C3 (D0), U3.2 (1B1)
/Expansion/D1: J1.C3, J2.C3, J3.C3, J4.C3, J5.C3, J6.C3, J7.C3, J8.C3, U1.B3 (D1), U3.3 (1B2)
/Expansion/D2: J1.A4, J2.A4, J3.A4, J4.A4, J5.A4, J6.A4, J7.A4, J8.A4, U1.C4 (D2), U3.5 (1B3)
/Expansion/D3: J1.C4, J2.C4, J3.C4, J4.C4, J5.C4, J6.C4, J7.C4, J8.C4, U1.A2 (D3), U3.6 (1B4)
/Expansion/D4: J1.A5, J2.A5, J3.A5, J4.A5, J5.A5, J6.A5, J7.A5, J8.A5, U1.A3 (D4), U3.8 (1B5)
/Expansion/D5: J1.C5, J2.C5, J3.C5, J4.C5, J5.C5, J6.C5, J7.C5, J8.C5, U1.A4 (D5), U3.9 (1B6)
/Expansion/D6: J1.A6, J2.A6, J3.A6, J4.A6, J5.A6, J6.A6, J7.A6, J8.A6, U1.A5 (D6), U3.11 (1B7)
/Expansion/D7: J1.C6, J2.C6, J3.C6, J4.C6, J5.C6, J6.C6, J7.C6, J8.C6, U1.A6 (D7), U3.12 (1B8)
/Expansion/D8: J1.A7, J2.A7, J3.A7, J4.A7, J5.A7, J6.A7, J7.A7, J8.A7, U1.B7 (D8), U3.13 (2B1)
/Expansion/D9: J1.C7, J2.C7, J3.C7, J4.C7, J5.C7, J6.C7, J7.C7, J8.C7, U1.A7 (D9), U3.14 (2B2)
/Expansion/D10: J1.A8, J2.A8, J3.A8, J4.A8, J5.A8, J6.A8, J7.A8, J8.A8, U1.A8 (D10), U3.16 (2B3)
/Expansion/D11: J1.C8, J2.C8, J3.C8, J4.C8, J5.C8, J6.C8, J7.C8, J8.C8, U1.A9 (D11), U3.17 (2B4)
/Expansion/D12: J1.A9, J2.A9, J3.A9, J4.A9, J5.A9, J6.A9, J7.A9, J8.A9, U1.A10 (D12), U3.19 (2B5)
/Expansion/D13: J1.C9, J2.C9, J3.C9, J4.C9, J5.C9, J6.C9, J7.C9, J8.C9, U1.A11 (D13), U3.20 (2B6)
/Expansion/D14: J1.A10, J2.A10, J3.A10, J4.A10, J5.A10, J6.A10, J7.A10, J8.A10, U1.A12 (D14), U3.22 (2B7)
/Expansion/D15: J1.C10, J2.C10, J3.C10, J4.C10, J5.C10, J6.C10, J7.C10, J8.C10, U1.A13 (D15), U3.23 (2B8)
/Expansion/D16: J1.B1, J2.B1, J3.B1, J4.B1, J5.B1, J6.B1, J7.B1, J8.B1, U1.B11 (D16), U4.2 (1B1)
/Expansion/D17: J1.B2, J2.B2, J3.B2, J4.B2, J5.B2, J6.B2, J7.B2, J8.B2, U1.A14 (D17), U4.3 (1B2)
/Expansion/D18: J1.B3, J2.B3, J3.B3, J4.B3, J5.B3, J6.B3, J7.B3, J8.B3, U1.B12 (D18), U4.5 (1B3)
/Expansion/D19: J1.B4, J2.B4, J3.B4, J4.B4, J5.B4, J6.B4, J7.B4, J8.B4, U1.A15 (D19), U4.6 (1B4)
/Expansion/D20: J1.B5, J2.B5, J3.B5, J4.B5, J5.B5, J6.B5, J7.B5, J8.B5, U1.A16 (D20), U4.8 (1B5)
/Expansion/D21: J1.B6, J2.B6, J3.B6, J4.B6, J5.B6, J6.B6, J7.B6, J8.B6, U1.A17 (D21), U4.9 (1B6)
/Expansion/D22: J1.B7, J2.B7, J3.B7, J4.B7, J5.B7, J6.B7, J7.B7, J8.B7, U1.B16 (D22), U4.11 (1B7)
/Expansion/D23: J1.B8, J2.B8, J3.B8, J4.B8, J5.B8, J6.B8, J7.B8, J8.B8, U1.C15 (D23), U4.12 (1B8)
/Expansion/D24: J1.B9, J2.B9, J3.B9, J4.B9, J5.B9, J6.B9, J7.B9, J8.B9, U1.A18 (D24), U4.13 (2B1)
/Expansion/D25: J1.B10, J2.B10, J3.B10, J4.B10, J5.B10, J6.B10, J7.B10, J8.B10, U1.C16 (D25), U4.14 (2B2)
/Expansion/D26: J1.B11, J2.B11, J3.B11, J4.B11, J5.B11, J6.B11, J7.B11, J8.B11, U1.B18 (D26), U4.16 (2B3)
/Expansion/D27: J1.B12, J2.B12, J3.B12, J4.B12, J5.B12, J6.B12, J7.B12, J8.B12, U1.D16 (D27), U4.17 (2B4)
/Expansion/D28: J1.B13, J2.B13, J3.B13, J4.B13, J5.B13, J6.B13, J7.B13, J8.B13, U1.C18 (D28), U4.19 (2B5)
/Expansion/D29: J1.B14, J2.B14, J3.B14, J4.B14, J5.B14, J6.B14, J7.B14, J8.B14, U1.E16 (D29), U4.20 (2B6)
/Expansion/D30: J1.B15, J2.B15, J3.B15, J4.B15, J5.B15, J6.B15, J7.B15, J8.B15, U1.E17 (D30), U4.22 (2B7)
/Expansion/D31: J1.B16, J2.B16, J3.B16, J4.B16, J5.B16, J6.B16, J7.B16, J8.B16, U1.D18 (D31), U4.23 (2B8)
/GND_{L}: U1.C6 (GND), U1.C7 (GND), U1.C9 (GND), U1.C11 (GND), U1.C13 (GND), U1.K3 (GND), U1.K16 (GND), U1.L3 (GND), U1.M16 (GND), U1.R4 (GND), U1.R11 (GND), U1.R13 (GND), U1.S10 (GND), U1.T4 (GND)
/GND_{O}: U1.B2 (GND), U1.B4 (GND), U1.B6 (GND), U1.B8 (GND), U1.B10 (GND), U1.B13 (GND), U1.B15 (GND), U1.B17 (GND), U1.D2 (GND), U1.D17 (GND), U1.F2 (GND), U1.F17 (GND), U1.H2 (GND), U1.H17 (GND), U1.L2 (GND), U1.L17 (GND), U1.N2 (GND), U1.N17 (GND), U1.Q2 (GND), U1.Q17 (GND), U1.S2 (GND), U1.S15 (GND), U1.S17 (GND)
/GND_{P}: U1.R6 (GND), U1.R10 (GND), U1.S9 (GND)
/Memory/CDONE: D1.2 (A), R1.1, U2.65 (CDONE)
/Memory/DRAM_A0: J9.12 (A0), J10.12 (A0), J11.12 (A0), J12.12 (A0), U2.37 (IOB_56)
/Memory/DRAM_A1: J9.13 (A1), J10.13 (A1), J11.13 (A1), J12.13 (A1), U2.38 (IOB_57)
/Memory/DRAM_A2: J9.14 (A2), J10.14 (A2), J11.14 (A2), J12.14 (A2), U2.39 (IOB_61)
/Memory/DRAM_A3: J9.15 (A3), J10.15 (A3), J11.15 (A3), J12.15 (A3), U2.41 (IOB_63)
/Memory/DRAM_A4: J9.16 (A4), J10.16 (A4), J11.16 (A4), J12.16 (A4), U2.42 (IOB_64)
/Memory/DRAM_A5: J9.17 (A5), J10.17 (A5), J11.17 (A5), J12.17 (A5), U2.43 (IOB_71)
/Memory/DRAM_A6: J9.18 (A6), J10.18 (A6), J11.18 (A6), J12.18 (A6), U2.44 (IOB_72)
/Memory/DRAM_A7: J9.28 (A7), J10.28 (A7), J11.28 (A7), J12.28 (A7), U2.47 (IOB_79)
/Memory/DRAM_A8: J9.31 (A8), J10.31 (A8), J11.31 (A8), J12.31 (A8), U2.49 (IOB_81_GBIN5)
/Memory/DRAM_A9: J9.32 (A9), J10.32 (A9), J11.32 (A9), J12.32 (A9), U2.52 (IOB_82_GBIN4)
/Memory/DRAM_A10: J9.19 (A10), J10.19 (A10), J11.19 (A10), J12.19 (A10), U2.45 (IOB_73)
/Memory/DRAM_A11: J9.29 (A11), J10.29 (A11), J11.29 (A11), J12.29 (A11), U2.48 (IOB_80)
/Memory/DRAM_BUF_DIR: U3.1 (1DIR), U3.24 (2DIR), U4.1 (1DIR), U4.24 (2DIR)
/Memory/DRAM_BUF_~OE: U3.25 (*2OE), U3.48 (*1OE), U4.25 (*2OE), U4.48 (*1OE)
/Memory/DRAM_D0: J9.2 (DQ0), J10.2 (DQ0), J11.2 (DQ0), J12.2 (DQ0), U3.47 (1A1)
/Memory/DRAM_D1: J9.4 (DQ1), J10.4 (DQ1), J11.4 (DQ1), J12.4 (DQ1), U3.46 (1A2)
/Memory/DRAM_D2: J9.6 (DQ2), J10.6 (DQ2), J11.6 (DQ2), J12.6 (DQ2), U3.44 (1A3)
/Memory/DRAM_D3: J9.8 (DQ3), J10.8 (DQ3), J11.8 (DQ3), J12.8 (DQ3), U3.43 (1A4)
/Memory/DRAM_D4: J9.20 (DQ4), J10.20 (DQ4), J11.20 (DQ4), J12.20 (DQ4), U3.41 (1A5)
/Memory/DRAM_D5: J9.22 (DQ5), J10.22 (DQ5), J11.22 (DQ5), J12.22 (DQ5), U3.40 (1A6)
/Memory/DRAM_D6: J9.24 (DQ6), J10.24 (DQ6), J11.24 (DQ6), J12.24 (DQ6), U3.38 (1A7)
/Memory/DRAM_D7: J9.26 (DQ7), J10.26 (DQ7), J11.26 (DQ7), J12.26 (DQ7), U3.37 (1A8)
/Memory/DRAM_D8: J9.49 (DQ8), J10.49 (DQ8), J11.49 (DQ8), J12.49 (DQ8), U3.36 (2A1)
/Memory/DRAM_D9: J9.51 (DQ9), J10.51 (DQ9), J11.51 (DQ9), J12.51 (DQ9), U3.35 (2A2)
/Memory/DRAM_D10: J9.53 (DQ10), J10.53 (DQ10), J11.53 (DQ10), J12.53 (DQ10), U3.33 (2A3)
/Memory/DRAM_D11: J9.55 (DQ11), J10.55 (DQ11), J11.55 (DQ11), J12.55 (DQ11), U3.32 (2A4)
/Memory/DRAM_D12: J9.57 (DQ12), J10.57 (DQ12), J11.57 (DQ12), J12.57 (DQ12), U3.30 (2A5)
/Memory/DRAM_D13: J9.61 (DQ13), J10.61 (DQ13), J11.61 (DQ13), J12.61 (DQ13), U3.29 (2A6)
/Memory/DRAM_D14: J9.63 (DQ14), J10.63 (DQ14), J11.63 (DQ14), J12.63 (DQ14), U3.27 (2A7)
/Memory/DRAM_D15: J9.65 (DQ15), J10.65 (DQ15), J11.65 (DQ15), J12.65 (DQ15), U3.26 (2A8)
/Memory/DRAM_D16: J9.3 (DQ16), J10.3 (DQ16), J11.3 (DQ16), J12.3 (DQ16), U4.47 (1A1)
/Memory/DRAM_D17: J9.5 (DQ17), J10.5 (DQ17), J11.5 (DQ17), J12.5 (DQ17), U4.46 (1A2)
/Memory/DRAM_D18: J9.7 (DQ18), J10.7 (DQ18), J11.7 (DQ18), J12.7 (DQ18), U4.44 (1A3)
/Memory/DRAM_D19: J9.9 (DQ19), J10.9 (DQ19), J11.9 (DQ19), J12.9 (DQ19), U4.43 (1A4)
/Memory/DRAM_D20: J9.21 (DQ20), J10.21 (DQ20), J11.21 (DQ20), J12.21 (DQ20), U4.41 (1A5)
/Memory/DRAM_D21: J9.23 (DQ21), J10.23 (DQ21), J11.23 (DQ21), J12.23 (DQ21), U4.40 (1A6)
/Memory/DRAM_D22: J9.25 (DQ22), J10.25 (DQ22), J11.25 (DQ22), J12.25 (DQ22), U4.38 (1A7)
/Memory/DRAM_D23: J9.27 (DQ23), J10.27 (DQ23), J11.27 (DQ23), J12.27 (DQ23), U4.37 (1A8)
/Memory/DRAM_D24: J9.50 (DQ24), J10.50 (DQ24), J11.50 (DQ24), J12.50 (DQ24), U4.36 (2A1)
/Memory/DRAM_D25: J9.52 (DQ25), J10.52 (DQ25), J11.52 (DQ25), J12.52 (DQ25), U4.35 (2A2)
/Memory/DRAM_D26: J9.54 (DQ26), J10.54 (DQ26), J11.54 (DQ26), J12.54 (DQ26), U4.33 (2A3)
/Memory/DRAM_D27: J9.56 (DQ27), J10.56 (DQ27), J11.56 (DQ27), J12.56 (DQ27), U4.32 (2A4)
/Memory/DRAM_D28: J9.58 (DQ28), J10.58 (DQ28), J11.58 (DQ28), J12.58 (DQ28), U4.30 (2A5)
/Memory/DRAM_D29: J9.60 (DQ29), J10.60 (DQ29), J11.60 (DQ29), J12.60 (DQ29), U4.29 (2A6)
/Memory/DRAM_D30: J9.62 (DQ30), J10.62 (DQ30), J11.62 (DQ30), J12.62 (DQ30), U4.27 (2A7)
/Memory/DRAM_D31: J9.64 (DQ31), J10.64 (DQ31), J11.64 (DQ31), J12.64 (DQ31), U4.26 (2A8)
/Memory/DRAM_R/~W: J9.47 (R/~W), J10.47 (R/~W), J11.47 (R/~W), J12.47 (R/~W)
/Memory/FLASH_MISO: U2.68 (IOB_106_SDI), U5.2 (DO(IO1))
/Memory/FLASH_MOSI: U2.67 (IOB_105_SDO), U5.5 (DI(IO0))
/Memory/FLASH_SCK: R3.1, U2.70 (IOB_107_SCK), U5.6 (CLK)
/Memory/FLASH_SS: R2.1, U2.71 (IOB_108_SS), U5.1 (~CS)
/Memory/~RAS0: J9.44 (~RAS0), J10.44 (~RAS0), J11.44 (~RAS0), J12.44 (~RAS0), U2.60 (IOB_95)
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

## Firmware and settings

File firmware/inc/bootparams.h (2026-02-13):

#pragma once

#include <stdint.h>

struct bp_record {
    uint16_t tag;       // tag ID
    uint16_t size;      // size of record (in bytes)
    uint32_t data[];    // data
};

struct mem_info {
    uint32_t addr;      // physical address of memory chunk
    uint32_t size;      // length of memory chunk (in bytes)
};

struct user_image {
    uint32_t addr;      // physical address of user image
    uint32_t size;      // length of user image
    uint32_t vaddr;     // user virtual base address
    uint32_t entry;     // executable virtual entry address
};

#define BP_LAST         0x0000  // list record (sentinel)
#define BP_MACHTYPE     0x0001  // machine type
#define BP_CPUTYPE      0x0002  // cpu type
#define BP_FPUTYPE      0x0003  // fpu type
#define BP_MMUTYPE      0x0004  // mmu type
#define BP_MEMCHUNK     0x0005  //memory chunk address and size
                                // (struct mem_info)
#define BP_RAMDISK      0x0006  // ramdisk address and size
                                // (struct mem_info)
#define BP_COMMAND_LINE 0x0007  // kernel command line parameters
                                // (string)

// A random seed used to initialize the RNG:
// - length    [2 bytes, 16-bit big endian]
// - seed data [`length` bytes, padded to preserve 4-byte struct alignment]
#define BP_RNG_SEED     0x0008

#define BP_USERIMAGE    0x0009  // krnL4 user image
                                // (struct user_image)

/* Linux/m68k Architectures (BP_MACHTYPE) */
#define MACH_A68040PC   1

/* CPU, FPU, MMU types (BP_CPUTYPE, BP_FPUTYPE, BP_MMUTYPE) */

#define CPUB_68020      0
#define CPUB_68030      1
#define CPUB_68040      2
#define CPUB_68060      3
#define CPUB_COLDFIRE   4

#define CPU_68020       (1 << CPUB_68020)
#define CPU_68030       (1 << CPUB_68030)
#define CPU_68040       (1 << CPUB_68040)
#define CPU_68060       (1 << CPUB_68060)
#define CPU_COLDFIRE    (1 << CPUB_COLDFIRE)

#define FPUB_68881      0
#define FPUB_68882      1
#define FPUB_68040      2   /* Internal FPU */
#define FPUB_68060      3   /* Internal FPU */
#define FPUB_SUNFPA     4   /* Sun-3 FPA */
#define FPUB_COLDFIRE   5   /* ColdFire FPU */

#define FPU_68881       (1 << FPUB_68881)
#define FPU_68882       (1 << FPUB_68882)
#define FPU_68040       (1 << FPUB_68040)
#define FPU_68060       (1 << FPUB_68060)
#define FPU_SUNFPA      (1 << FPUB_SUNFPA)
#define FPU_COLDFIRE    (1 << FPUB_COLDFIRE)

#define MMUB_68851      0
#define MMUB_68030      1   /* Internal MMU */
#define MMUB_68040      2   /* Internal MMU */
#define MMUB_68060      3   /* Internal MMU */
#define MMUB_APOLLO     4   /* Custom Apollo */
#define MMUB_SUN3       5   /* Custom Sun-3 */
#define MMUB_COLDFIRE   6   /* Internal MMU */

#define MMU_68851       (1 << MMUB_68851)
#define MMU_68030       (1 << MMUB_68030)
#define MMU_68040       (1 << MMUB_68040)
#define MMU_68060       (1 << MMUB_68060)
#define MMU_SUN3        (1 << MMUB_SUN3)
#define MMU_APOLLO      (1 << MMUB_APOLLO)
#define MMU_COLDFIRE    (1 << MMUB_COLDFIRE)

#define BOOTPARAMSV_MAGIC           0x4250561A  /* 'BPV^Z' */
#define MK_BP_VERSION(major,minor)  (((major) << 16) + (minor))
#define BP_VERSION_MAJOR(v)         (((v) >> 16) & 0xffff)
#define BP_VERSION_MINOR(v)         ((v) >> & 0xffff)

struct __attribute__((packed)) bootversion {
    uint16_t branch;
    uint32_t magic;
    struct {
        uint32_t machtype;
        uint32_t version;
    } machversions[];
};

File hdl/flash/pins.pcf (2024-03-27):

set_io	clk		94
set_frequency clk	33
set_io	rst		52
set_io	led		95
set_io	btn		93

set_io	dbg1		60
set_io	dbg2		62
set_io	dbg3		61

set_io	spi_mosi	67
set_io	spi_miso	68
set_io	spi_sck		70
set_io	spi_ss		71
set_io	spi_io2		64
set_io	spi_io3		63

set_io	d_dir		110
set_io	d_oe		112

set_io	ts		45
set_io	tip		47
set_io	tbi		31
set_io	tci		32
set_io	tea		33
set_io	ta		34

set_io	tt[0]		49
set_io	tt[1]		48

set_io	tm[0]		41
set_io	tm[1]		39
set_io	tm[2]		38

set_io	IPL[0]		98
set_io	IPL[1]		99
set_io	IPL[2]		101

set_io	rw		44
set_io	siz[0]		43
set_io	siz[1]		42

set_io	DSACK[0]	96
set_io	DSACK[1]	97
set_io	RESIZ_CS	104
set_io	RESIZ_DS	56

set_io	COM_CS		102
set_io	COM_IRQ		55
set_io	COM_IACK	105
set_io	RAM_CS		106
set_io	AVEC		107

set_io	a[0]		91
set_io	a[1]		90
set_io	a[2]		88
set_io	a[3]		87
set_io	a[4]		85
set_io	a[5]		84
set_io	a[6]		82
set_io	a[7]		83
set_io	a[8]		10
set_io	a[9]		11
set_io	a[10]		29
set_io	a[11]		28
set_io	a[12]		26
set_io	a[13]		25
set_io	a[14]		24
set_io	a[15]		22
set_io	a[16]		23
set_io	a[17]		21
set_io	a[18]		18
set_io	a[19]		19
set_io	a[20]		16
set_io	a[21]		12
set_io	a[22]		81
set_io	a[23]		17
set_io	a[24]		78
set_io	a[25]		15
set_io	a[26]		80
set_io	a[27]		75
set_io	a[28]		79
set_io	a[29]		74
set_io	a[30]		76
set_io	a[31]		73

set_io 	d[0]		138
set_io 	d[1]		136
set_io 	d[2]		139
set_io 	d[3]		135
set_io 	d[4]		137
set_io 	d[5]		141
set_io 	d[6]		142
set_io 	d[7]		143
set_io 	d[8]		144
set_io 	d[9]		1
set_io 	d[10]		2
set_io 	d[11]		3
set_io 	d[12]		4
set_io 	d[13]		7
set_io 	d[14]		8
set_io 	d[15]		9
set_io 	d[16]		134
set_io 	d[17]		130
set_io 	d[18]		129
set_io 	d[19]		128
set_io 	d[20]		125
set_io 	d[21]		124
set_io 	d[22]		122
set_io 	d[23]		121
set_io 	d[24]		120
set_io 	d[25]		119
set_io 	d[26]		118
set_io 	d[27]		117
set_io 	d[28]		116
set_io 	d[29]		115
set_io 	d[30]		114
set_io 	d[31]		113

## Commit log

2023-08-22 rough draft 68040 symbol, pga179 footprint
    [68040pc.kicad_pcb, 68040pc.kicad_sch]
2023-08-22 add rough draft SIMM-72 symbol/footprint
2023-08-25 fix symbols/footprints
2023-08-25 add atx outline, begin DRAM schematic
    [68040pc.kicad_pcb, 68040pc.kicad_sch, memory.kicad_sch]
2023-08-26 more memory wiring
    [68040pc.kicad_pcb, 68040pc.kicad_sch, memory.kicad_sch]
2023-08-27 lock position of expansion slots
    [68040pc.kicad_pcb, 68040pc.kicad_sch, DIN96SBSS2.5.stp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]
2023-08-29 make my own 3D models for connectors
    [DIN96PBRS2.8.FCStd, DIN96SBSS2.5.FCStd, DIN96SBSS2.step]
2023-08-29 fix slot orientation (slot 1 only)\nTodo.. fix other slots
    [68040pc.kicad_pcb]
2023-09-01 fix EXP connector positioning
    [68040pc.kicad_pcb, 68040pc.kicad_sch, memory.kicad_sch]
2023-09-10 Add 3d models, re-place exp slots, add components
    [15-48-0106.stp, 68040pc.kicad_pcb, 68040pc.kicad_sch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]
2023-09-25 more ideas, add motherboard drawing draft
    [board.dxf]
2023-10-23 resize board to Baby-AT
    [68040pc.kicad_pcb, board.dxf]
2023-11-14 reformat expanison port symbol
    [expansion.kicad_sch]
2023-11-14 reconfigure expansion slot schematic
    [68040pc.kicad_pcb, 68040pc.kicad_sch, expansion.kicad_sch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]
2023-11-27 begin work on a simpler first draft board
    [68040pc.kicad_pcb, 68040pc.kicad_sch, expansion.kicad_sch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]
2023-12-09 update cpu symbol, topology
    [68040pc.kicad_sch, fpga.kicad_sch, memory.kicad_sch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]
2023-12-10 add interrupt logic, clean up modules
    [68040pc.kicad_pcb, 68040pc.kicad_sch, expansion.kicad_sch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]
2023-12-18 getting closer
    [68040pc.kicad_sch, cf.kicad_sch, fpga.kicad_sch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]
2023-12-22 re-design level shifters
    [68040pc.kicad_sch, clock.kicad_sch, fpga.kicad_sch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]
2024-02-25 restructure, create minimum board project
    [15-48-0106.stp, 68040pc.kicad_pcb, 68040pc.kicad_sch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]
2024-02-26 work on testboard, move 3d models
    [68040pc.kicad_sch, clock.kicad_sch, cpu.kicad_sch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]
2024-02-27 work on testboard
    [cpu.kicad_sch, datatrx.kicad_sch, fpga.kicad_sch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]
2024-02-27 root mostly finished
    [cpu.kicad_sch, datatrx.kicad_sch, fpga.kicad_sch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]
2024-03-04 simpleboard nearly complete
    [clock.kicad_sch, cpu.kicad_sch, datatrx.kicad_sch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]
2024-03-06 fix up FPGA pinning
    [fpga.kicad_sch, fpga_abuf.kicad_sch, testboard.kicad_pcb]
2024-03-06 I ripped it all apart
    [datatrx.kicad_sch, decode.kicad_sch, fpga.kicad_sch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]
2024-03-10 testboard - schematic and route done
    [clock.kicad_sch, cpu.kicad_sch, fpga.kicad_sch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]
2024-03-11 create BOM, still needs more
    [bom.csv]
2024-03-13 make 3.3v reg bigger
    [fpga.kicad_sch, power.kicad_sch, testboard.kicad_pcb]
2024-03-14 layout FTDI
    [fpga.kicad_sch, power.kicad_sch]
2024-03-15 finish routing testboard
    [fpga.kicad_sch]
2024-03-15 remove duplicate LV_A0 track
    [fpga.kicad_sch]
2024-03-16 Gerbers published, board out for production!
    [fpga.kicad_sch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]
2024-03-20 fix interrupt checks, create stack-free putc/puts
2024-03-24 update errata for testboard
    [fpga.kicad_sch, resizer.kicad_sch]
2024-03-24 initial commit: reading flash through FPGA
    [bom.csv]
2024-03-29 Move UART init up and write test char
2024-03-29 start integrating UART & RAM
2024-03-29 update to Kicad 8.0
    [clock.kicad_sch, cpu.kicad_sch, fpga.kicad_sch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]
2024-04-02 hasty interrupt button addition
2024-04-03 start implementing circular buffer for uart
2024-04-04 add printf source repository
2024-04-04 printf working with tx circular buffer
2024-04-04 add interrupt path for UART
2024-05-04 create interrupt module
2024-05-07 commit to save this version of interrupt interface
2024-05-07 interrupt peripheral works, need to adjust firmware
2024-05-13 fix firmware interrupt test
2024-05-19 add receive support to uart
2025-03-02 trying to get uart to work properly
2026-01-18 integrate startup code to zero bss (_startup.c), copy init data. switch to building elf->bin. alter memory map. still troubleshooting DUART.
2026-01-31 fix incorrect sp restore; use `stop` to die
2026-05-03 make the LED CPU controllable
2026-05-04 add simple TX-only UART peripheral
2026-05-04 add FPGA UART RX
